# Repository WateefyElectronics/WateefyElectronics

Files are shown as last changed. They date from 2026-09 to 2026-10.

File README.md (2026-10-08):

<p align="center">
  Wateefy Electronics
</p>

<h1 align="center">Quality Engineered Electronics</h1>

<p align="center"><strong>Hardware documentation, firmware images and release mirrors.</strong></p>

---

## About

**One person. No corners cut.**

Wateefy Electronics is a one-person hardware shop building pixel-lighting gear that survives the season that kills the cheap stuff.

It started with boards that kept dying. Lighting hardware fails in predictable ways: a shorted run takes the whole board, a supply gets wired backwards for two seconds, a strip is hot-plugged and the inductive kick walks through the regulator. None of that is exotic. It is a normal season in a real installation, and most boards have nothing standing in the path to stop any of it.

So I taught myself PCB design and built the board I wanted to own — one where every failure mode has a specific part in front of it, chosen from a datasheet and verified against the copper. That board became the NODE family. The engineering discipline comes from infrastructure that is not allowed to fall over; the lights are where I get to have fun with it.

There is no team to hide behind. If something is wrong, it is on me, and I will make it right.

### How I build

**Protection first — assume it gets abused.** Reverse polarity, transients, shorted runs, backwards supplies. The board is designed for the bad day, not the bench. Nothing in the power path runs near its limit.

**Honest specs — numbers you can check.** Real ratings, real derating, real trade-offs stated out loud. No vaporware, no spec-sheet trophies that fall apart when someone does the math.

**Serviceable — repair, don't replace.** Fuses you swap by hand. A board meant to be fixed and kept running, not thrown out when one channel dies.

**Open to the community.** Docs and board definitions live here on GitHub, with mounting files as they are released. This gear is for the xLights and WLED crowd, built alongside them.

That approach scales across the catalog: pixel controllers, power distribution and injection, and whatever the next problem turns out to be.

This repository is the public documentation for that hardware. It is not the design source — schematics and layout are not published here.

---

## The NODE Platform

The NODE family is our line of addressable pixel controllers. Three boards share one power and protection architecture, differing only in how the MCU is powered and mounted — the protected power section is the product, and the module is a consumable.

| | **NODE Mini** | **NODE Flex** | **NODE Backbone** |
|---|---|---|---|
| **Control transport** | Wi-Fi | Per installed module | Wired Ethernet with PoE |
| **MCU** | Seeed XIAO ESP32-S3, socketed | Any ESP32 DevKit on 0.9″ or 1.0″ row spacing | Waveshare ESP32-S3-ETH-POE, socketed |
| **Logic power** | Onboard buck regulator from the pixel supply | Onboard buck regulator from the pixel supply | Power over Ethernet, independent of the pixel supply |
| **Built for** | Single zones on straightforward Wi-Fi sites | Mixed-hardware fleets and module obsolescence | Large installations where Wi-Fi contention becomes the limit |

### Shared architecture

Most controllers have one power rail. Input voltage lands on a terminal and it is the same copper that reaches the strips — whatever arrives, arrives everywhere at once.

NODE splits power into three isolated domains, each on its own copper plane:

1. **Dirty power in.** The input terminal is assumed hostile, isolated to the smallest region of the board possible, with nothing downstream touching it directly.
2. **Clean power.** Bidirectional transient clamping and an active reverse-polarity blocker sit between dirty and clean. Reverse the supply and the pass element never turns on — no current path, nothing sacrificed, red indicator explains why. Correct the wiring and it recovers on its own.
3. **The protected distribution bus.** Clean power passes the main fuse to become the bus. Each of the eight outputs taps that bus through its own fuse. A fault on run six opens one fuse and the other seven never notice.

Four levels of protection sit between the screw terminal and the pixels — clamp, active block, main fuse, channel fuse — each on its own copper. That is why these are four-layer boards with a split inner power plane rather than two layers and one pour.

### Common to every board

- 8 independent output channels — WS281x / SK6812 / TM1814 family, 5 V level-shifted drive
- 5–48 VDC input, no voltage jumper — one board runs 5, 12, 24 and 36 V pixel systems with nothing to set wrong
- 30 A through the board at standard 1 oz copper — not a paid upgrade
- One fuse per output channel, eight channels, no sharing
- Non-destructive reverse-polarity protection — nothing is consumed when someone wires it backwards
- Four-port DMX-512 / RS-485 output with per-port transient protection, one port receive-capable
- Per-channel data ESD protection chosen for low junction capacitance, so it does not round off WS281x bit timing on long runs
- Conformal coated at the fab — protects against moisture and humidity, with connectors, sockets, fuse clips and switches masked
- Runs WLED — pre-built images maintained for each board, no proprietary control protocol, no vendor lock-in

### Serviceable by design

Three things on these boards can be killed by field abuse, and all three pull out by hand.

**The fuse** is a mini blade — the same part sold in a variety pack at any auto parts counter. **The buffer** is a jellybean octal logic IC in a DIP socket, and the socket accepts either of two common logic families, so whichever one is in stock works. **The MCU** is a socketed module: seat another and carry on. No hot air, no braid, no scrap board.

That is what the board area buys. Blade holders, a DIP socket and terminal clearance cost real estate — room to get an iron in, room to pull a fuse without tweezers, room to reach the reset button without unmounting anything. Compact is easy. Compact and serviceable at high current is a different problem, and this is the side of it we chose. A channel that dies at eight o'clock on the twenty-third of December should be a fifteen-minute drive, not a three-day wait.

---

## Node Power

Controllers are half the problem. The other half is getting clean, protected power to where the pixels actually are — and the same three-domain thinking applies there too.

**Node Power is coming.** Details when the boards are ready, and not a day before.

---

## Documentation

Specifications are maintained per board, not in this README.

| Document | Covers |
|---|---|
| [NODE Platform Reference](./Node%20Pixel%20Controllers/README.md) | Power architecture, input protection, output stage, environmental and build data — common to all three boards. Also available as [PDF](./Node%20Pixel%20Controllers/NODE-Common-V1a.pdf) |
| [NODE Mini](./Node%20Pixel%20Controllers/Node%20Mini) | Variant specification — XIAO ESP32-S3 socket, onboard logic rail, GPIO map |
| [NODE Flex](./Node%20Pixel%20Controllers/Node%20Flex) | Variant specification — universal DevKit carrier, jumper channel mapping, module compatibility |
| [NODE Backbone](./Node%20Pixel%20Controllers/Node%20Backbone) | Variant specification — Ethernet and PoE, W5500 network stack, isolated logic domain |
| [NODE Enclosures](./Node%20Enclosures/) | Free 3D-printable enclosures: Aegis, Bastion 350, Citadel 600 |
| [Datasheets](./Datasheets) | Product datasheets in PDF |

Read the Platform Reference for how the board protects your pixels. Read the variant specification for the differences between boards.

---

## Firmware

Pre-built WLED images, configured for each board's GPIO map.

- [Node Mini (XIAO)](./Firmware/Node%20Mini/README.md)
- [Node Backbone (Waveshare)](./Firmware/Node%20Backbone/README.md)
- [All mirrored releases](https://github.com/johnvoipguy/WateefyElectronics/releases)

Images are built and maintained per board — Backbone needs its own Ethernet build, and the XIAO runs a modified build to match the Mini's GPIO map. Flash what is published here rather than a generic release.

WLED, ESPHome and ESPixelStick are properties of the ESP32 silicon, not of the carrier board, so any of them will run on any NODE board. What differs is which pre-built image ships, and how much GPIO the board's own hardware has already spent before your channels get any.

Flashing requires `esptool`. See the [firmware directory](./Firmware) for the procedure.

---

## Repository layout

```
Datasheets/               Product datasheets (PDF)
Firmware/                 Pre-built WLED images and flashing instructions
Node Enclosures/          3D-printable enclosures (3MF), photos and specs
Node Pixel Controllers/   Platform reference and per-board specifications
images/                   Product and documentation imagery
releases/                 Release notes and mirrors
```

---

## Compatibility

**LED protocols:** WS2811, WS2812/B, WS2813, WS2815, WS2816, SK6812/RGBW, TM1814, and other single-wire families supported by WLED.

**Control protocols:** E1.31/sACN, Art-Net, DDP, MQTT and the HTTP/JSON API, per WLED. DMX-512 over RS-485 on the onboard transceiver ports.

---

## Status

The NODE family is pre-release. Current hardware is a validation build — first-article boards for bring-up, characterisation and field trial. Documentation in this repository tracks that hardware and will change as revisions are finalised.

---

## Support

Open an [issue](https://github.com/johnvoipguy/WateefyElectronics/issues) for documentation errors, firmware problems or hardware questions.

---

## Accepted limitations

Stated plainly rather than buried:

- **Not automotive qualified.** Protection targets transients credible in a residential or light-commercial installation. Not tested to ISO 7637 load-dump profiles, and not intended for vehicle use.
- **Over-voltage beyond specification is not survivable.** A supply above the rated input range will conduct the input TVS and open the main fuse. This is sacrificial by design — the board is protected, and the TVS and fuse are treated as consumables.
- **No enclosure is included with the board.** Four corner mounting holes are provided for whatever the installation already uses, or print one of the free [NODE Enclosures](./Node%20Enclosures/).
- **The ecosystem is new.** Established alternatives exist with years of community documentation behind them. Each board's specification names them directly and states plainly where they are the better choice.

---

## Firmware Downloads

Use this quick selector:

- **Node Mini (XIAO)** → [Go to Mini downloads](./Firmware/Node%20Mini/README.md)
- **Node Backbone (Waveshare)** → [Go to Backbone downloads](./Firmware/Node%20Backbone/README.md)

Or browse all mirrored releases directly:  
https://github.com/johnvoipguy/WateefyElectronics/releases

<sub>© 2026 Wateefy Electronics. Specifications subject to change.</sub>

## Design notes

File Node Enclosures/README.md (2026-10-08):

# NODE Enclosures

### 3D-Printable Enclosures for the NODE Family

*Wateefy Electronics*

---

> **Free to print. Built to take the weather.**

**Document rev:** 1.0 · **Date:** 2026-10-08

---

## Overview

Three printable enclosures for NODE controllers, designed and test-printed in-house. Each
one has a fitted lid, a gland wall for every cable, and shrouded vents for an optional fan.

The print files (3MF) are free in this repository. Printed enclosures are also available in the
store, either bundled with a controller or on their own for anyone without a printer.

| | **NODE Aegis** | **NODE Bastion 350** | **NODE Citadel 600** |
|---|---|---|---|
| **Holds** | Any NODE board | NODE board + Mean Well LRS-350 | NODE board + Mean Well LRS-600 |
| **Dimensions (L × W × H)** | 187 × 153 × 46 mm | 275 × 175 × 91 mm | 275 × 175 × 99 mm |
| **Power input** | 1 × PG9 gland | 1 × PG9 gland | 1 × PG9 gland |
| **Pixel outputs** | 8 × PG7 glands | 8 × PG7 glands | 8 × PG7 glands |
| **Fan mount (optional 5 V fan)** | 3010 holes printed in | 3010 / 4010 holes printed in | 3010 / 4010 holes printed in |
| **Venting** | Shrouded vents | Shrouded vents | Shrouded vents |
| **PSU rail mounts** | — | Printable, included | Printable, included |
| **Lid** | Included | Included | Included |

---

## Common to All Three

- **Fasteners (not included):** every screw hole is printed with an M4 thread. Printed threads
  vary with printer accuracy, so use M4 self-tapping screws. Recommended lengths are 6 mm for
  the lid, and 4 mm for the NODE controller and the PSU rails.
- **Lid seal:** the top edge of the shell is stepped. A raised inner lip, about 1 mm wide and
  1.5 mm tall, runs inside the ring of screw holes and seats into a matching groove in the lid.
  The screw holes sit outside that lip, so water coming through a screw hole (loose, stripped
  or missing screw) can't get past the lid joint into the enclosure.
- **Glands:** 1 × PG9 for power in, 8 × PG7 for the pixel runs, one gland per channel.
- **Fan:** mounting holes for the fan are designed into the print: 3010 on the Aegis, 3010 or 4010
  on the Bastion and Citadel. The fan itself is optional, 5 V, and sits behind a printed vent
  shroud. The shrouds stay in place with or without a fan.
- **Ethernet (NODE Backbone, or NODE Flex with an Olimex or ETH01 module):** no Ethernet hole is pre-cut. Drill one for an M25 gland, or
  whatever size your cable and jack need.

<p align="center">
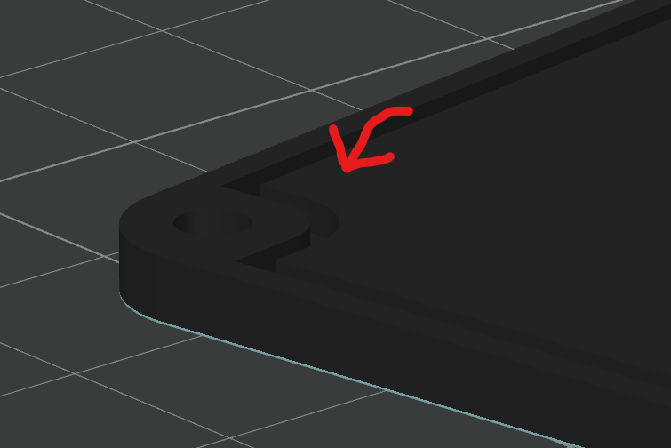
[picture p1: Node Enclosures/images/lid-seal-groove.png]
Lid underside: groove that receives the shell's inner lip
  
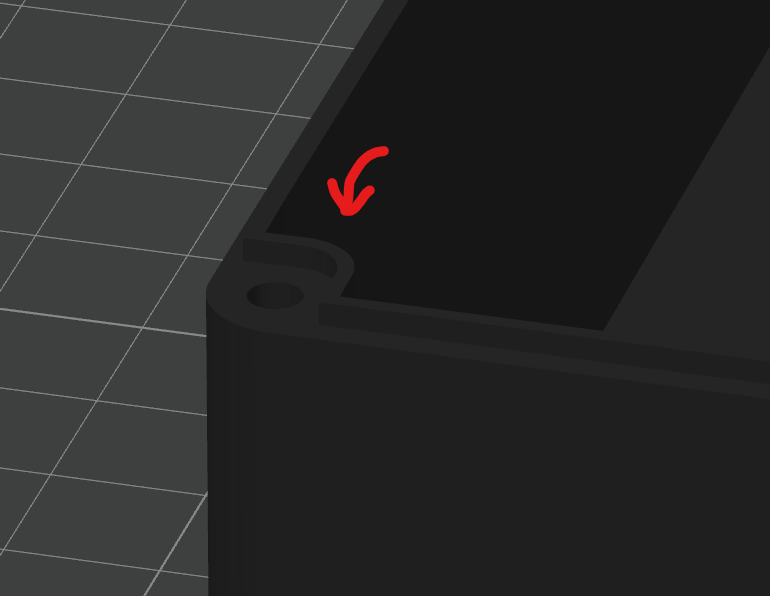
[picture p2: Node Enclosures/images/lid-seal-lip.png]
Shell top edge: raised inner lip inside the screw holes
  
</p>
<p align="center"><em>Lid seal. Left: groove in the lid. Right: inner lip on the shell, inside the screw holes.</em></p>

---

## NODE Aegis

The bare-bones enclosure. Fits any NODE controller, with no onboard PSU. Use it when power
comes from a supply mounted elsewhere.

<p align="center">
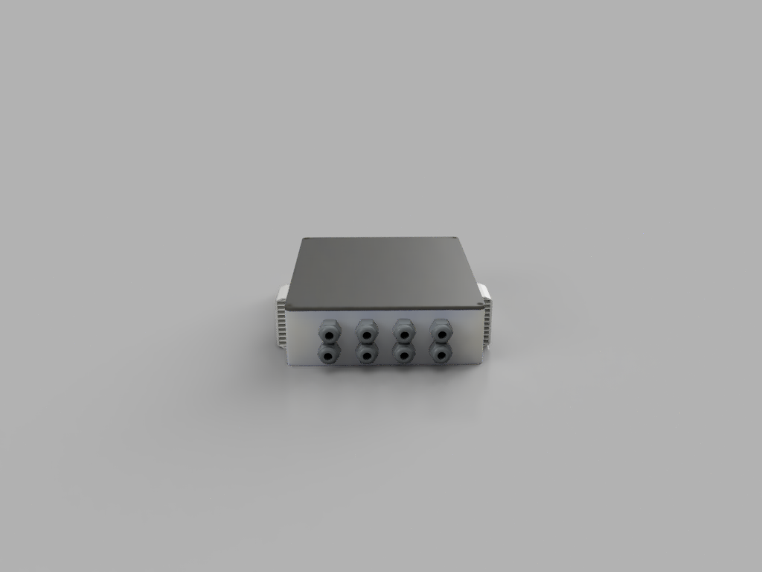
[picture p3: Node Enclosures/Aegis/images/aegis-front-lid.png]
NODE Aegis, lid on, gland wall
  
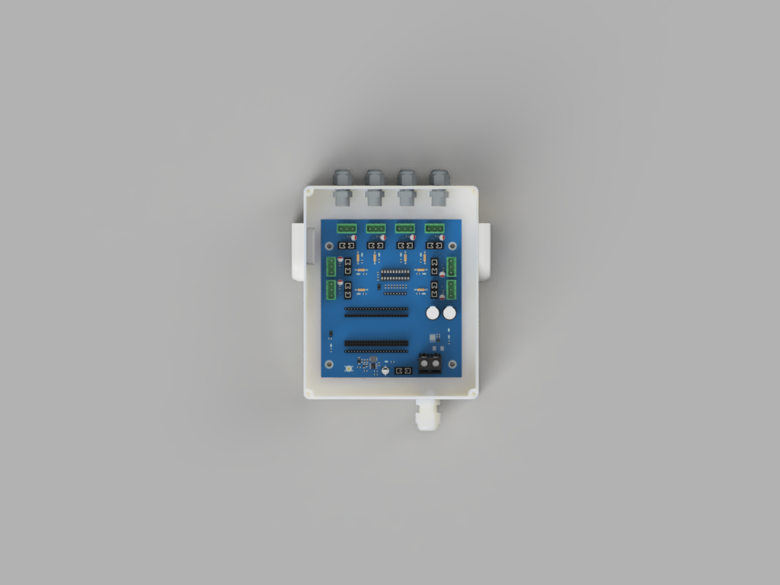
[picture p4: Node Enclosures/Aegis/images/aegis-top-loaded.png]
NODE Aegis with controller installed
  
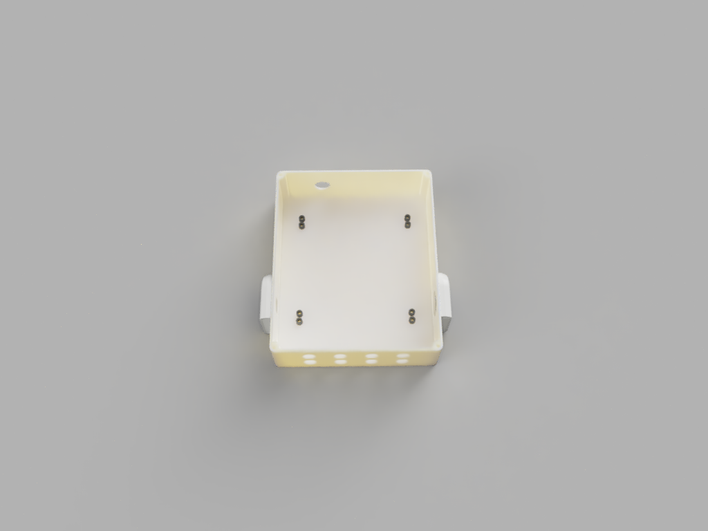
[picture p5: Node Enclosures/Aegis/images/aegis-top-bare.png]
NODE Aegis, empty shell
  
</p>

| | |
|---|---|
| Dimensions | 187 × 153 × 46 mm (L × W × H) |
| Fan | 3010 mounting holes printed in; 5 V fan optional |
| Files | [`Aegis/`](./Aegis/) |

---

## NODE Bastion 350

Controller and supply in one box. Built around the **Mean Well LRS-350**, which sits on
printable rails with the NODE board above it.

<p align="center">
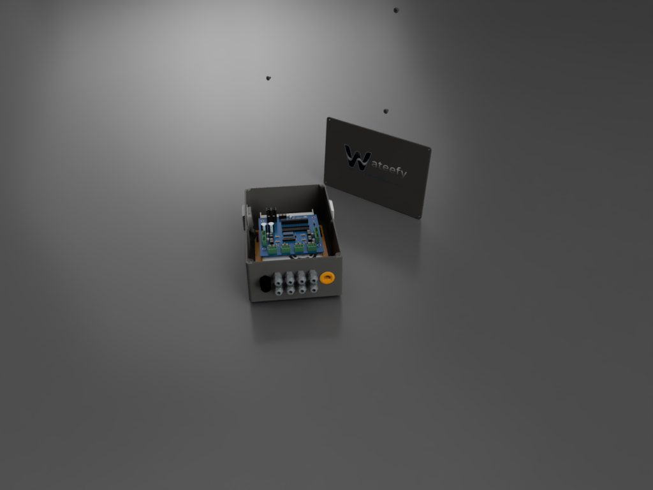
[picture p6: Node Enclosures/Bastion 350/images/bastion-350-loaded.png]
NODE Bastion 350 with controller and PSU
  
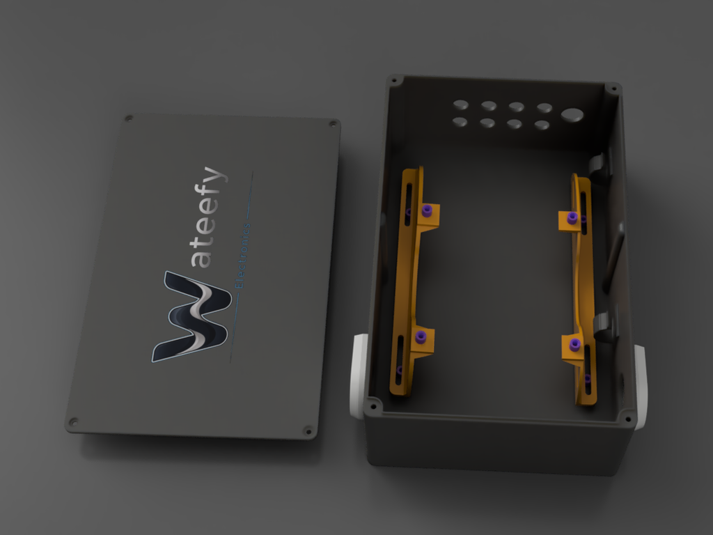
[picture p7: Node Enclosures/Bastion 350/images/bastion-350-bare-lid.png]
NODE Bastion 350 shell, PSU rails and lid
  
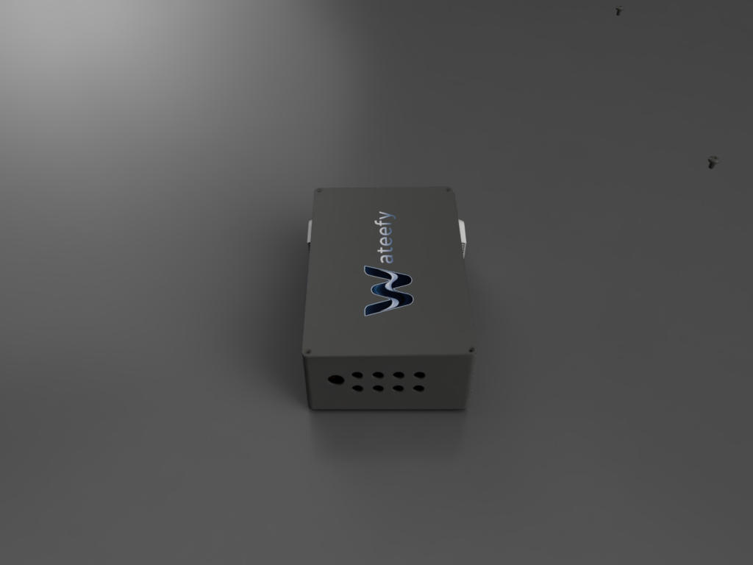
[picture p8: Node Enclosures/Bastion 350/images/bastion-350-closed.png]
NODE Bastion 350, lid on
  
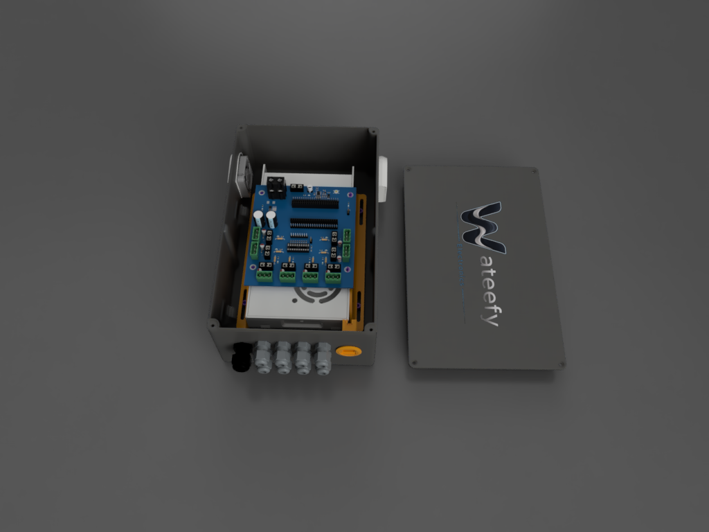
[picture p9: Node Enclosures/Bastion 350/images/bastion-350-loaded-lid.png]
NODE Bastion 350 loaded, lid alongside
  
</p>

| | |
|---|---|
| Dimensions | 275 × 175 × 91 mm (L × W × H) |
| PSU | Mean Well LRS-350, on included printable rail mounts |
| Fan | 3010 / 4010 mounting holes printed in; 5 V fan optional |
| Files | [`Bastion 350/`](./Bastion%20350/) |

---

## NODE Citadel 600

The large one. Same footprint as the Bastion, but taller to clear the **Mean Well LRS-600**.

<p align="center">
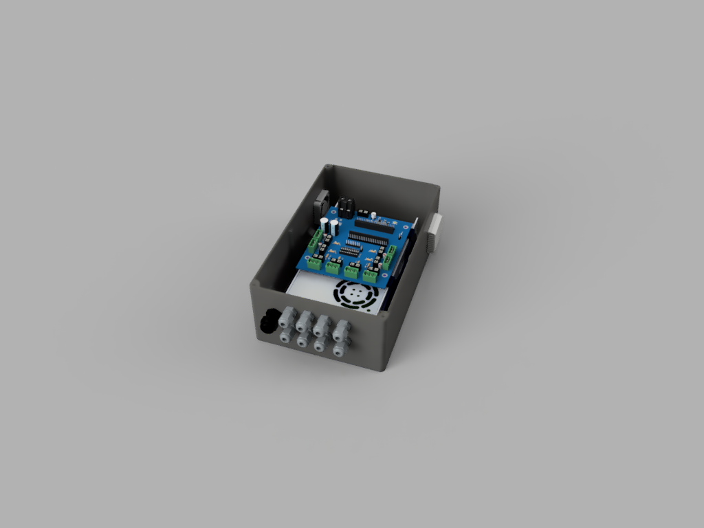
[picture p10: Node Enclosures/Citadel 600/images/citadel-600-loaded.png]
NODE Citadel 600 with controller and PSU
  
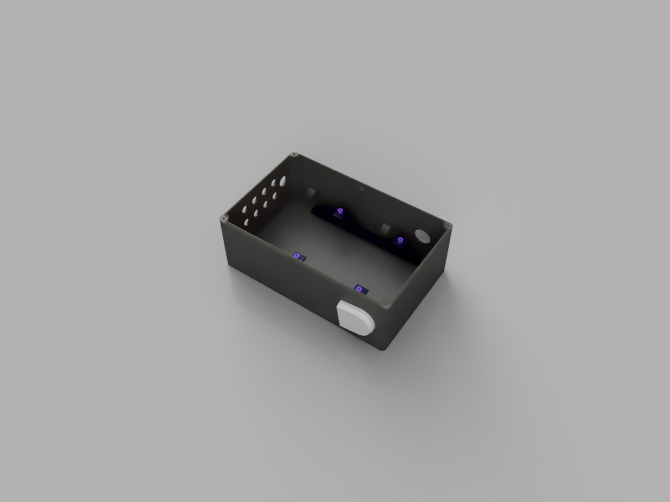
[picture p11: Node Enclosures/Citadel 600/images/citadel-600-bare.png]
NODE Citadel 600, empty shell
  
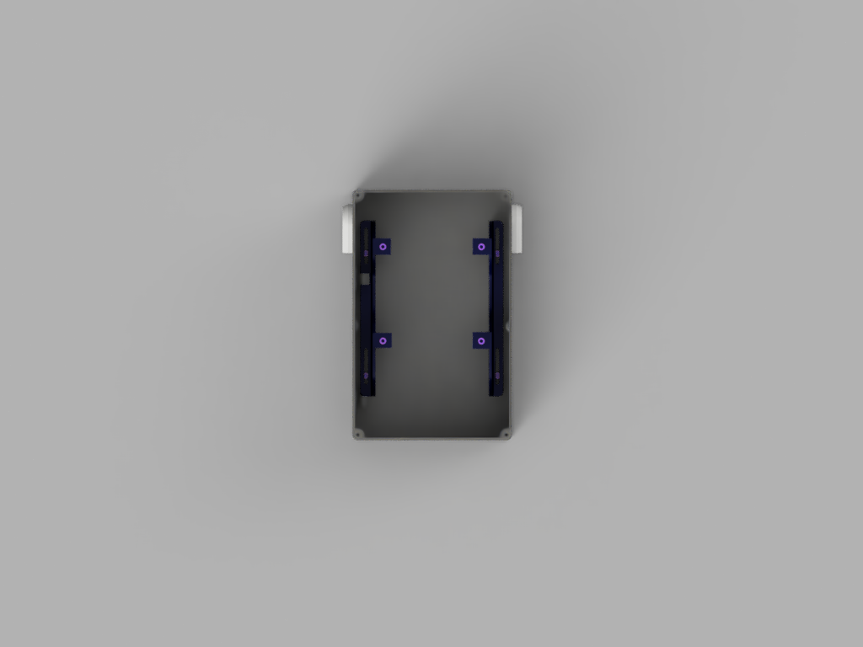
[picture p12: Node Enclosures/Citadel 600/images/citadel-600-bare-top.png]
NODE Citadel 600, top view with PSU rails
  
</p>

| | |
|---|---|
| Dimensions | 275 × 175 × 99 mm (L × W × H) |
| PSU | Mean Well LRS-600, on included printable rail mounts |
| Fan | 3010 / 4010 mounting holes printed in; 5 V fan optional |
| Files | [`Citadel 600/`](./Citadel%20600/) |

---

## Files

Each enclosure folder holds its print-ready 3MF and reference photos:

```
Node Enclosures/
├── README.md
├── Aegis/
│   ├── NODE-Aegis-Enclosure.3mf
│   └── images/
├── Bastion 350/
│   ├── NODE-Bastion-350-Enclosure.3mf
│   └── images/
└── Citadel 600/
    ├── NODE-Citadel-600-Enclosure.3mf
    └── images/
```

---

## Printing

The 3MFs are slicer project files with every part laid out on its plates: the shell, the lid,
the vent shrouds, and on the Bastion and Citadel the PSU rails. They were saved with these
reference settings:

| Setting | Value |
|---|---|
| Material | PETG |
| Nozzle | 0.4 mm |
| Layer height | 0.2 mm |
| Walls | 2 |
| Infill | 15 % |
| Supports | None |

The profile was saved on a Qidi X-Plus 5. Re-slice for your own printer. Any slicer that
reads 3MF will import the geometry.

---

*Wateefy Electronics · NODE Enclosures · Rev 1.0*

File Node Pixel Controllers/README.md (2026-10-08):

# NODE Platform

### Hardware Reference · 8-Channel Addressable LED Controller Family

*Wateefy Electronics*

---

> **The power section is the product. The module is a consumable.**

**Document rev:** 3.0 · **Board rev:** V1a · **Date:** 2026-08-06

---

## Scope

This document covers the hardware common to every board in the NODE family — power
architecture, input protection, output stage, environmental data and build process. It applies
to **NODE Mini**, **NODE Flex** and **NODE Backbone** alike.

What differs between variants — the MCU module, the logic rail source, board dimensions,
GPIO mapping and per-board accepted limitations — is documented in each board's own
**Variant Specification**. Where a variant departs from anything stated here, its supplement
says so explicitly in *Deltas from the Platform Reference*.

Read this document for how the board protects your pixels. Read the supplement for which
board to buy.

---

## 1. Power Architecture

Three separate domains, each on its own copper region:

| Domain | Boundary | What it carries |
|---|---|---|
| **Input (unprotected)** | Screw terminal → ideal-diode stage | Raw supply. Assumed hostile. Transient clamp sits across this node. |
| **Clean (protected)** | Ideal-diode output → main fuse | Reverse-blocked, surge-clamped. Bulk capacitance lives here. |
| **Distribution bus (fused)** | Main fuse → 8 channel fuses + logic regulator | Everything downstream taps this bus through its own fuse. |

## 2. Input & Protection

| Parameter | Value | Notes |
|---|---|---|
| Input voltage range | 5 – 48 VDC | Single rail, powers both pixels and onboard logic |
| Input connector | WECO 158-A-111/02, 2-pole screw terminal | 57 A / 10 mm² rated; 30 A design maximum = 53% of rating |
| Maximum continuous current | 30 A | At standard 1 oz outer copper — no copper upgrade required |
| Main fuse | 30 A mini blade, Keystone 3568 holder | Holder rated 30 A / 500 V; user-replaceable |
| Reverse-polarity protection | LM74700-Q1 ideal-diode controller + CSD18540Q5B | FET held off under reverse input; no current path to load; non-sacrificial and self-recovering |
| Pass element | CSD18540Q5B NexFET | 60 V V<sub>DS</sub>, 205 A I<sub>D</sub>, ~2.2 mΩ R<sub>DS(on)</sub> — 15% of current rating at 30 A design load |
| Input transient clamp | SMCJ48CA bidirectional TVS, 1500 W | 48 V standoff, 53.3 V breakdown; conducts in neither direction at rated input |
| Bulk capacitance | 2 × 1000 µF, 63 V | On the clean rail, downstream of the ideal diode |
| Ideal-diode charge pump | 22 nF, 100 V | VCAP to ANODE, floating — not referenced to ground |
| Ideal-diode hold-up | 47 µF electrolytic, 80 V | Between controller and pass FET, per reference design |
| Polarity indication | Anti-parallel green/red LED pair | Green = correct, red = reversed; shared 1 kΩ limit; LED reverse stress 2 V against 5 V rating |

**Voltage headroom summary:** **36 V nominal, 48 V absolute maximum.** Every component in the power path is rated **63 V or above**; every semiconductor is **60 V or above**.

**Derating against input voltage.** Utilization of each component's own rating. **5 V, 12 V and 24 V are the mainstream pixel voltages** and are shown in bold:

| Component | Rating | **5 V** | **12 V** | **24 V** | 36 V | 48 V |
|---|---|---|---|---|---|---|
| Bulk input capacitors | 63 V | **8 %** | **19 %** | **38 %** | 57 % | 76 % |
| Channel output caps | 80 V | **6 %** | **15 %** | **30 %** | 45 % | 60 % |
| Ideal-diode hold-up | 80 V | **6 %** | **15 %** | **30 %** | 45 % | 60 % |
| Buck input electrolytic | 80 V | **6 %** | **15 %** | **30 %** | 45 % | 60 % |
| HV-plane ceramics | 100 V | **5 %** | **12 %** | **24 %** | 36 % | 48 % |
| Ideal-diode controller | 65 V | **8 %** | **18 %** | **37 %** | 55 % | 74 % |
| Pass MOSFET V<sub>DS</sub> | 60 V | **8 %** | **20 %** | **40 %** | 60 % | 80 % |
| Buck regulator V<sub>IN</sub> | 80 V | **6 %** | **15 %** | **30 %** | 45 % | 60 % |

At the **36 V nominal** rating no part on the plane exceeds 60 % of its own limit. At the **48 V absolute maximum** nothing exceeds 80 %. On the 5 V, 12 V and 24 V strips that carry the overwhelming majority of installations, the entire plane runs under 40 %.

## 3. Outputs

| Parameter | Value | Notes |
|---|---|---|
| Channels | 8 | Independent, individually fused — no shared fuses |
| Output connector | Phoenix MKDS-series 3-pole, per channel | V+ / DATA / GND; 12 A rated → 63% at the 7.5 A fitted fuse, 83% at the 10 A maximum |
| Per-channel fuse | 7.5 A mini blade fitted, 10 A maximum — Keystone 3568 holder | 25% of holder rating at 7.5 A, 33% at 10 A; user-replaceable |
| Level translation | SN74HCT541 octal buffer, DIP-20 socket | 3.3 V drive vs 2.0 V V<sub>IH</sub> = 1.3 V margin |
| Data series resistance | 330 Ω, axial through-hole, per channel | Limits fault current back into the buffer |
| Data ESD protection | PESD5V0F1BL, per channel, connector side | 0.4–0.55 pF junction capacitance; RC ≈ 181 ps — no measurable effect on WS281x bit timing |
| Data drive current | ≈ 4 mA per channel | 67% of ±6 mA buffer rating |
| Buffer supply current | ≈ 45 mA total | 64% of 70 mA device maximum |
| Per-channel decoupling | 47 µF electrolytic 80 V + 100 nF ceramic 100 V | Local to each output connector |
| Channel activity indication | One LED per channel, 470 Ω limited | ≈ 5 mA, 25% of LED rating |

## 4. Environmental & Compliance

| Parameter | Value |
|---|---|
| Operating temperature | −20 °C to +60 °C *(design target; not qualification tested)* |
| Substrate rating | UL-recognized, JLC-1 marking |
| RoHS | Compliant |
| Workmanship | IPC Class 2 |
| Electrical test | Flying-probe, 100% of boards |
| Traceability | 2D barcode serial number, per board |

## Mounting & Enclosure

**No enclosure is included with the board, but three are available.** The [NODE Enclosures](../Node%20Enclosures/) are free to 3D-print from this repository, or can be bought printed from the store, on their own or bundled with a controller. **NODE Aegis** holds the board alone. **NODE Bastion 350** and **NODE Citadel 600** hold the board together with a Mean Well LRS-350 or LRS-600 supply. All three have a gland wall for power in and eight pixel runs, a sealed lid joint, and printed mounts for an optional 5 V fan.

The board still mounts just as well in whatever the installation already uses: a CG1500, a DIN rail, a weatherproof box, a plywood backer.

What NODE adds instead is **conformal coating**, applied after assembly with connectors, sockets, fuse clips, and switches masked. Competing boards in this class ship uncoated. A coated board in a vented enclosure tolerates condensation and humidity in a way a bare board does not, which matters for the seasonal outdoor installs this was built for.

Four corner mounting holes are provided. *Hole spacing and a downloadable mount STL: to be published at first article.*

---

## Build & Assurance

- **Fabrication** — 4-layer, 1.6 mm, high-T<sub>g</sub> substrate, ENIG finish, epoxy-filled and capped vias, IPC Class 2 workmanship
- **Assembly** — professional SMT assembly, flying-probe electrical test on 100% of boards
- **Traceability** — 2D barcode serial on every board; UL-recognized substrate marking
- **Coating** — conformal coating applied after assembly, with connectors, sockets, fuse clips, and switches masked
- **Design review** — every net verified against manufacturer datasheets; schematics independently reviewed by two automated analysis passes with human verification of every finding

---

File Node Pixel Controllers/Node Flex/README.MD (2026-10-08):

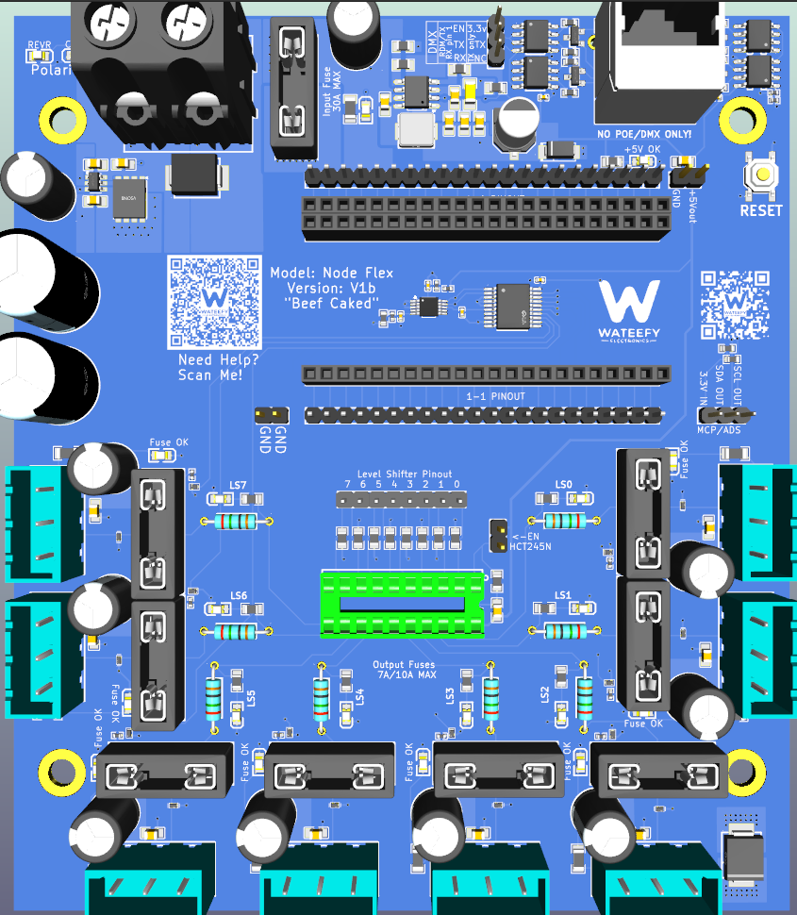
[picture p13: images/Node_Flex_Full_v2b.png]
 

                          V1                                                                   V1b

# NODE Flex

### 8-Channel Addressable LED Controller · Universal Module Carrier

*Wateefy Electronics*

> **One board. Whatever module is in the drawer.**

---

## At a Glance

- **8 independent output channels** — WS281x / SK6812 / TM1814 family, 5 V level-shifted drive
- **Any ESP32 DevKit on 0.9″ or 1.0″ row spacing** — both spacings on the board, up to 22 positions per row, jumper-mapped to the outputs
- **5–48 VDC input, no voltage jumper** — nothing to set wrong, ever
- **30 A through the board at standard copper** — not a paid upgrade
- **Three isolated power domains** — dirty input, clean protected power, fused distribution bus
- **A fuse on every single output** — eight channels, eight fuses, no sharing
- **Non-destructive reverse-polarity protection** — nothing is consumed when someone wires it backwards
- **Four-port DMX-512 / RS-485 output** — per-port transient protection, one port receive-capable
- 123 × 138 mm · 4-layer · ENIG · conformal coated

---

## Why This Exists

Every ESP32 DevKit has a different pinout. Every controller board is hard-wired to exactly one of them. So the board you bought last year is scrap when that module goes end-of-life, and the four dev boards in your parts drawer are useless because none of them match the footprint someone else chose.

NODE Flex breaks that dependency by defining compatibility as **geometry rather than a part number**. The board carries both of the common DevKit row spacings — 0.9 inch and 1.0 inch — with up to 22 positions in each row. Module length does not matter: a 2×15 or 2×19 board seats in the same sockets and simply leaves positions empty. A jumper field then decides which module pin drives which output channel.

The practical result is that the compatibility list cannot go stale. If a module lands on 0.9″ or 1.0″ centres, it fits — including modules that do not exist yet. When your favourite DevKit is discontinued, and it will be, you seat a different one and keep going. Same board, same protection, same firmware.

For anyone maintaining an installed base across mixed hardware, this is the SKU that ends the inventory problem.

---

## The Architecture: Three Power Domains

Most controllers have one power rail. Input voltage lands on a terminal and it is the same copper that reaches your strips. Whatever arrives — spike, reverse polarity, sag, transient — arrives everywhere at once.

NODE splits power into three separate domains on their own copper planes:

**1 · Dirty power in.** The input terminal accepts whatever the supply, the wiring, and the person doing the wiring hand it. This domain is assumed hostile, isolated to the smallest region of the board possible, and nothing downstream touches it directly.

**2 · Clean power.** Between dirty and clean sits the protection stage: bidirectional transient clamping and an active reverse-polarity blocker. Reverse the supply and the pass element never turns on — no current path to the rest of the board, nothing sacrificed, red indicator tells you why. Correct the wiring and it recovers on its own.

**3 · The protected bus.** Clean power passes the main fuse to become the distribution bus. Each of the eight output channels taps that bus through its own fuse. A fault on run six opens one fuse and the other seven never notice.

> **BEEFCAKE.**
> The pass element is an 80 V MOSFET whose current rating is several times the board's 30 A design load. It will never be the thing that fails.

**Decoupling where the current actually is.** Two thousand microfarads of bulk sits on the protected bus, and another forty-seven at every single output connector. The distribution is the point: one reservoir at the input cannot cover the harness inductance of eight separate output runs no matter how large it is. When a full-white frame lands on all eight channels at once, each channel draws from its own reserve sitting centimetres from its terminal.

Four levels between the screw terminal and your pixels — clamp, active block, main fuse, channel fuse — each on its own copper. That is why this is a four-layer board with a split inner power plane rather than two layers and one pour.

Nothing in the pixel power path is rated below **63 V** — and every semiconductor in it is **60 V or above** — against a 48 V absolute maximum input. Nothing in the chain runs near its limit.

At the **36 V nominal** rating, no component in the power path operates above **60 %** of its own rating. At the **48 V absolute maximum**, nothing exceeds **80 %**. On the 5 V, 12 V and 24 V strips that carry the overwhelming majority of installations, the entire plane runs under **40 %**. It is not a number anyone else in this class publishes, and it is the reason to believe the rest of this page.

---

## What Else You Actually Get

**Defined-state inputs.** Because a channel's jumper may legitimately be left unset, every buffer input carries a pull-down resistor. An unconfigured channel sits at a known logic low instead of floating and driving whatever it feels like — which on a strip full of pixels means darkness rather than noise. This is the detail that separates a real universal carrier from a breakout board with headers.

**Data lines treated like data lines.** Each output runs through a series resistor and a sub-picofarad ESD device placed on the connector side, where transients actually arrive. The low-capacitance part was chosen deliberately: a fat protection diode on a data line rounds off WS281x bit timing and produces a controller that works on the bench and sparkles on a 40-foot run.

**DMX where you need it.** Four RS-485 ports on RJ45, each with its own transceiver and its own transient protection, alongside the eight pixel channels.

> **Three things on this board can be killed by field abuse. All three pull out by hand.**
>
> **The fuse.** A mini blade — the same part sold in a variety pack at every gas station, auto parts counter and big-box store in the country. Pulls with fingers, costs pennies. Not a cartridge you order online and wait for.
>
> **The buffer.** A jellybean octal logic IC in a DIP socket. It sits directly behind your wiring, which makes it the part most likely to die and the part most annoying to replace anywhere else. Here it lifts out with a fingernail. And the socket accepts either of two common octal logic families — a strap on pin 1 handles the output-enable behaviour of one and the direction pin of the other — so you fit whichever is in stock. Supply-chain resilience on a fifty-cent line item sounds trivial right up until the next shortage.
>
> **The MCU.** A socketed module. Blow it up, seat another. No hot air, no braid, no scrap board.
>
> Nobody else in this class can claim all three.

And that is what the board area buys. Blade holders, a DIP socket, and terminal clearance cost real estate — there is room to get an iron in, room to pull a fuse without tweezers, room to reach the reset button without unmounting anything, and room at the terminals for heavy wire with ferrules. Compact is easy. Compact *and serviceable* at 30 A is a different problem, and this is the side of it we chose. A channel that dies at eight o'clock on the twenty-third of December should be a fifteen-minute drive, not a three-day wait.

**Serviceable by design.** The level shifter sits in a DIP socket. The DevKit sits in headers. Fuses pull by hand. Through-hole parts dominate the power section on purpose — this board is meant to be repaired, not replaced.

---

## Where It Goes

- **Mixed-hardware installations** — one controller SKU across a fleet built from whatever modules were available that year
- **Development and evaluation** — swap modules against a known-good, fully protected carrier
- **Long-life deployments** — the board outlives the module generation it was built around
- **Distributed whole-property displays** — one node per zone, eight runs each, scale by adding nodes

---

## How It Compares

*Comparison basis.* The closest peer is the Bong69 8 Port LED Distro — same idea, power and data integrated on one board, eight ports, WLED, sold at maker scale. QuinLED's Dig-Quad is the other reference point. Competitor figures are taken from the vendors' own published FAQ and specification pages as of July 2026 and should be re-verified before publication.

Athom's WLED range is deliberately excluded: single-strip and PWM controllers aimed at room-level and audio-reactive use. Different product, different buyer.

| | **NODE Flex** | **Bong69 8 Port LED Distro** | **QuinLED-Dig-Quad v3** |
|---|---|---|---|
| Output channels | 8 | 8 | 4 |
| MCU compatibility | Any DevKit on 0.9″ or 1.0″ row spacing, any length up to 22 positions | Fixed — WT32-ETH01 integrated | Fixed footprint — QuinLED-ESP32 or D1 Mini 32 |
| Survives module obsolescence | Yes — jumper a different DevKit | No — board is the module | No |
| Input range, one SKU | 5–48 VDC | V4: 12–48 V (5 V support dropped) · V3: 5–24 V (discontinued) | 5–24 VDC |
| Covers 5/12/24/36 V pixels | Yes, one board | No — requires choosing a version | Jumper-selectable up to 24 V; 36 V not supported |
| Input voltage selection | None — nothing to set wrong | Per board version | Jumper; vendor warns wrong setting "will fry the onboard components" |
| Input connector | Enclosed 57 A screw terminal | V4: spade connectors on a stud | Screw terminal |
| Continuous current, standard copper | 30 A | Not published | 15 A at 1 oz (30 A only with paid 2 oz upgrade) |
| Per-channel fuse rating | 7.5 A nominal · 10 A max per output | 5 A (V4) · 4 A hold / 8 A trip polyfuse (V3) | 10 A max recommended |
| Fuses on outputs | 8 — one per channel | 8 — one per channel | 5 fuses across 7 outputs (channels share) |
| Reverse-polarity protection | Active blocking — non-destructive, self-recovering | Not published | Parallel diode with fuse — sacrificial |
| Input transient clamp | Bidirectional TVS across the input | Not published | Not published |
| Data-line ESD protection | Per channel, sub-pF device | Series resistor only (33 Ω) | Not published |
| Power domain separation | 3 domains: dirty in / clean / fused bus | Not published | Single rail |
| Unconfigured input handling | Pull-down on all 8 buffer inputs | n/a — fixed pinout | n/a — fixed pinout |
| DMX-512 / RS-485 output | 4 ports, individually protected | Not published | Not published |
| Level shifter | 8-channel, socketed DIP | Not published | 4-channel, soldered |
| Conformal coating | Yes, applied at the fab | Not offered | Not offered |
| Fuse-status indicator | Per-channel LED | Blue "good fuse" LED per channel | Per board |
| Onboard USB programming | Via the module's own port | Onboard USB-C — required, the ESP is soldered down | Via the module's own port |
| Field-replaceable MCU | Yes — socketed module | No — ESP32-WROOM soldered to the board | Yes — socketed module |
| Fuse replacement | Mini blade — auto parts store, gas station, variety pack | Cartridge in a surface-mount holder — order online | ATO blade — auto parts store |
| Audio-reactive / mic support | DIY — headers fitted, spare GPIO available | DIY — wire an INMP441 to the H1 header (documented) | Analog audio input broken out |
| Temperature sensor support | DIY — headers fitted, spare GPIO available | DIY — add header, DS18B20 and 4.7 kΩ (documented) | Optional onboard footprint |
| Enclosure | Free 3D-printable [NODE Enclosures](../../Node%20Enclosures/), with or without an integrated PSU | None — 3D-print mounts published | None — bare board |
| Board size | 123 × 138 mm — the cost of blade holders, a DIP socket and terminal clearance | ~110 × 70 mm | ~100 × 50 mm |
| Firmware | WLED / ESPHome / ESPixelStick — module-level, not board-level | Same | Same |
| Firmware image | Pre-built image supplied per module | Pre-built image supplied; ESPixelStick needs the vendor hardware profile | Stock WLED builds |
| Ecosystem | New | Established, reviewed, xLights docs | Large, mature, well documented |

*A note on firmware comparisons.* WLED, ESPHome, and ESPixelStick are properties of the ESP32 silicon, not of the carrier board — any of them will run on any of these products. What actually differs is which pre-built image ships, and how much GPIO the board's own hardware has already spent before your channels get any.

**Where the others are the better choice, plainly.** Bong69 ships a proven, well-reviewed board with onboard USB-C programming, per-fuse status LEDs, documented audio-reactive and temperature-sensor support, xLights integration notes, published 3D-print mounts, and boards that arrive pre-configured and tested. QuinLED brings a deep peripheral breakout and years of community documentation. Neither ecosystem exists here yet. If you want established products, buy theirs.

**Where NODE Flex is the better choice.** Every competing board *is* its module — when that ESP32 variant goes end-of-life, the board goes with it. NODE Flex is a carrier: the module is a consumable, the protected power section is the product. Add one board covering 5/12/24/36 V pixels with every part in the power path well below its rating — no version to pick, eight fuses for eight channels, an enclosed 57 A terminal instead of exposed lugs, and four levels of protection on separate copper.

**The honest summary:** buy Bong69 or QuinLED if you want the mature ecosystem and never intend to change modules. Buy Flex if you have four different DevKits in a drawer, or if you expect to still be maintaining this installation after the current module generation is gone.

---

## Mounting & Enclosure

**No enclosure is included with the board, but three are available.** The [NODE Enclosures](../../Node%20Enclosures/) are free to 3D-print from this repository, or can be bought printed from the store, on their own or bundled with a controller. **NODE Aegis** holds the board alone. **NODE Bastion 350** and **NODE Citadel 600** hold the board together with a Mean Well LRS-350 or LRS-600 supply. All three have a gland wall for power in and eight pixel runs, a sealed lid joint, and printed mounts for an optional 5 V fan.

The board still mounts just as well in whatever the installation already uses: a CG1500, a DIN rail, a weatherproof box, a plywood backer.

What NODE adds instead is **conformal coating, applied at the fabrication facility** with connectors, sockets, fuse clips, and switches masked. Competing boards in this class ship uncoated. A coated board in a vented enclosure tolerates condensation and humidity in a way a bare board does not, which matters for the seasonal outdoor installs this was built for.

Four corner mounting holes are provided. *Hole spacing and a downloadable mount STL: to be published at first article.*

---

## Build & Assurance

- **Fabrication** — 4-layer, 1.6 mm, high-T<sub>g</sub> substrate, ENIG finish, epoxy-filled and capped vias, IPC Class 2 workmanship
- **Assembly** — professional SMT assembly, flying-probe electrical test on 100% of boards
- **Traceability** — 2D barcode serial on every board; UL-recognized substrate marking
- **Coating** — conformal coating applied at the fab, with connectors, sockets, fuse clips, and switches masked
- **Design review** — every net verified against manufacturer datasheets; schematics independently reviewed by two automated analysis passes with human verification of every finding

---

## Ordering

| Item | Detail |
|---|---|
| Model | NODE Flex |
| Configuration | Assembled, tested, conformal coated |
| Included | Controller board, level shifter installed, fuses installed |
| Not included | Enclosure (free to print or sold separately, see [NODE Enclosures](../../Node%20Enclosures/)), ESP32 DevKit module, jumper shunts, 3-pin plug connectors, blade fuses beyond those fitted, power supply |
| Availability | Pre-release. The present build is a validation run — first-article hardware for bring-up, characterisation and field trial. |
| Price | TBD |
| Lead time | TBD |
| Warranty | TBD |

---
---

# NODE Flex — Technical Specification

**Document rev:** 3.0 · **Board rev:** V1a · **Date:** 2026-09-01

> **Components are specified by function and rating.** Specific manufacturers and part
> numbers are selected at build time and may change with availability; every substitution
> is held to the ratings stated here.

## 1. Power Architecture

Three separate domains, each on its own copper region:

| Domain | Boundary | What it carries |
|---|---|---|
| **Input (unprotected)** | Screw terminal → ideal-diode stage | Raw supply. Assumed hostile. Transient clamp sits across this node. |
| **Clean (protected)** | Ideal-diode output → main fuse | Reverse-blocked, surge-clamped. Bulk capacitance lives here. |
| **Distribution bus (fused)** | Main fuse → 8 channel fuses + logic regulator | Everything downstream taps this bus through its own fuse. |

## 2. Input & Protection

| Parameter | Value | Notes |
|---|---|---|
| Pixel input voltage range | 5 – 48 VDC | 36 V nominal, 48 V absolute maximum |
| Input connector | Enclosed 2-pole screw terminal | 57 A / 10 mm² rated; 30 A design maximum = 53% of rating |
| Maximum continuous current | 30 A | At standard 1 oz outer copper — no copper upgrade required |
| Main fuse | 30 A mini blade, user-replaceable | Holder rated 30 A / 500 V |
| Reverse-polarity protection | Ideal-diode controller driving a high-side N-channel pass FET | FET held off under reverse input; no current path to load; non-sacrificial and self-recovering |
| Pass element | 80 V N-channel MOSFET, low milliohm R<sub>DS(on)</sub> | Rated above the input clamp voltage, not below it; current rating several times the 30 A design load |
| Input transient clamp | Bidirectional TVS, 1500 W, 48 V standoff | Conducts in neither direction at rated input; polarity-independent |
| Bulk capacitance | 2 × 1000 µF, 63 V | On the clean rail, downstream of the ideal diode |
| Ideal-diode support | 100 V charge-pump capacitor, 80 V hold-up capacitor | Per the controller's reference design |
| Polarity indication | Anti-parallel green/red LED pair | Green = correct, red = reversed; shared limit resistor sized for the full input range |

**Voltage headroom summary: 36 V nominal, 48 V absolute maximum.** Every component in the power path is rated **63 V or above**; every semiconductor is **60 V or above**.

**Derating against input voltage.** Utilization of each component's own rating. **5 V, 12 V and 24 V are the mainstream pixel voltages** and are shown in bold:

| Component | Rating | **5 V** | **12 V** | **24 V** | 36 V | 48 V |
|---|---|---|---|---|---|---|
| Bulk input capacitors | 63 V | **8 %** | **19 %** | **38 %** | 57 % | 76 % |
| Channel output caps | 80 V | **6 %** | **15 %** | **30 %** | 45 % | 60 % |
| Ideal-diode hold-up | 80 V | **6 %** | **15 %** | **30 %** | 45 % | 60 % |
| HV-plane ceramics | 100 V | **5 %** | **12 %** | **24 %** | 36 % | 48 % |
| Ideal-diode controller | 65 V | **8 %** | **18 %** | **37 %** | 55 % | 74 % |
| Pass MOSFET V<sub>DS</sub> | 80 V | **6 %** | **15 %** | **30 %** | 45 % | 60 % |

At the **36 V nominal** rating no part on the plane exceeds 60 % of its own limit. At the **48 V absolute maximum** nothing exceeds 80 %. On the 5 V, 12 V and 24 V strips that carry the overwhelming majority of installations, the entire plane runs under 40 %.

## 3. 5 V Logic Rail

| Parameter | Value | Notes |
|---|---|---|
| Regulator | Wide-input synchronous buck, thermally-padded package | Sat on the distribution bus; 12 thermal vias under the pad |
| Absolute maximum input | 80 V class | Well above the 48 V absolute-maximum input |
| Switching frequency | 400 kHz | Set by a fixed timing resistor |
| Output voltage | 5.1 V nominal | Resistive divider against a 1.0 V reference |
| Output current capability | 2 A | Actual load ≈ 0.5 A → 25% utilization |
| Inductor | 15 µH, 3.0 A saturation, 2.5 A RMS | 79% of saturation rating at the full 2 A load |
| Output capacitance | 3 × 22 µF ceramic | Per regulator reference design |
| Input capacitance | 4.7 µF + 100 nF ceramic, 100 V X7R, plus 80 V electrolytic bulk | Rated for the full input range with derating headroom |
| 5 V rail clamp | Unidirectional TVS, 6 V standoff | Cathode to the +5 V rail, anode to ground |
| Minimum on-time margin | 2.7× at 36 V input | No frequency foldback anywhere in the input range |
| Manual reset | Momentary switch to regulator enable | Pull-up to the distribution bus |

## 4. Outputs

| Parameter | Value | Notes |
|---|---|---|
| Channels | 8 | Independent, individually fused — no shared fuses |
| Output connector | 3-pole pluggable terminal, per channel | V+ / DATA / GND; 12 A rated → 63% at the 7.5 A fitted fuse, 83% at the 10 A maximum |
| Per-channel fuse | 7.5 A mini blade fitted, 10 A maximum | 25% of holder rating at 7.5 A, 33% at 10 A; user-replaceable |
| Level translation | Octal logic buffer, DIP-20 socket | Accepts either of two common octal families; 3.3 V drive against a 2.0 V V<sub>IH</sub> = 1.3 V margin |
| Data series resistance | 330 Ω, axial through-hole, per channel | Limits fault current back into the buffer |
| Data ESD protection | Sub-picofarad ESD device, per channel, connector side | 0.4–0.55 pF junction capacitance; RC ≈ 181 ps — no measurable effect on WS281x bit timing |
| Data drive current | ≈ 4 mA per channel | 67% of the ±6 mA buffer rating |
| Buffer supply current | ≈ 45 mA total | 64% of the 70 mA device maximum |
| Per-channel decoupling | 47 µF electrolytic 80 V + 100 nF ceramic 100 V | Local to each output connector |
| Channel activity indication | One LED per channel | Data activity on that channel |
| Fuse-status indication | One LED per channel, fed from the post-fuse node | Lit = that channel's fuse is intact and the bus is live |
| Buffer input pull-downs | 10 kΩ to ground, all 8 inputs | Defines logic low when a channel jumper is not fitted; ~330 µA sink at logic high |

### 4b. DMX-512 / RS-485 Output

| Parameter | Value | Notes |
|---|---|---|
| Ports | 4 | RJ45, T568B pairing |
| Transceivers | One RS-485 transceiver per port | Driver enables tied to a shared enable net; transmit data shared across all four |
| Receive | Port 1 only | The remaining three ports are transmit-only by design |
| Port protection | TVS array on the connector-side net, plus series resistance per line | Clamp sits ahead of the series limiting, in that order |

## 5. MCU Interface & Firmware

| Parameter | Value |
|---|---|
| Module support | Any ESP32-family DevKit on a supported row spacing *(module not included)* |
| Supported row spacings | 0.9″ (22.86 mm) and 1.0″ (25.4 mm) — both provided on the board |
| Socket rows | 2.54 mm pitch, up to 22 positions per row |
| Module length | Not constrained — shorter modules (2×15, 2×19) seat in the same rows, leaving positions unused |
| Channel assignment | Jumper header maps module GPIO to each of the 8 buffer inputs |
| Unconfigured channels | Held low by pull-down — no floating inputs |
| Buffer enable | Strap-selectable buffer output enable |
| Firmware | WLED — pre-built image supplied, configured for the fitted module's GPIO map |
| Supported LED protocols | WS2811, WS2812/B, WS2813, WS2815, WS2816, SK6812/RGBW, TM1814, and other single-wire families supported by WLED |
| Connectivity | Per installed module — Wi-Fi 2.4 GHz, or wired Ethernet / PoE-Ethernet where the DevKit provides it |
| Verified Ethernet DevKits | WT32-ETH01, WT32-ETH01-EVO and WT32-ETH02-PLUS all sit on 0.9″ (22.86 mm) centres and seat directly, leaving one free socket row per side |
| Known non-fitting modules | Olimex and LilyGo boards use non-standard row spacings and will not seat directly — they require an adapter or hand-wiring. Check your module's row centres against 0.9″ / 1.0″ before ordering |
| Control protocols | Per WLED: E1.31/sACN, Art-Net, DDP, MQTT, HTTP/JSON API. DMX-512 over the onboard RS-485 ports |
| Additional I/O | Spare module GPIO broken out on fitted headers for I²C and SPI peripherals, plus 3.3 V / 5 V / GND / TX / RX. Availability depends on the fitted DevKit |

> **Integrator note:** confirm that the GPIO assigned to a channel is not a boot-strapping pin on your specific module, and is free of flash or PSRAM duties. Pin restrictions vary by module and remain the integrator's responsibility.

## 6. Physical

| Parameter | Value |
|---|---|
| PCB dimensions | 123 × 138 mm |
| PCB thickness | 1.6 mm |
| Layer count | 4 — signal / ground plane / split power plane / signal |
| Copper weight | 1 oz outer, 1 oz inner |
| Substrate | High-T<sub>g</sub> 155 °C |
| Surface finish | ENIG, 1 µ" gold |
| Via treatment | Epoxy filled and capped |
| Soldermask | Blue |
| Mounting | 4 × corner mounting holes, 3 mm |
| Mounting hole spacing | 107.9 × 103.8 mm |
| Enclosure | Free 3D-printable [NODE Enclosures](../../Node%20Enclosures/), with or without an integrated PSU |
| Net weight | TBD — measure at first article |
| Conformal coating | Applied at the fab; connectors, sockets, fuse clips, and switches masked |

## 7. Environmental & Compliance

| Parameter | Value |
|---|---|
| Operating temperature | −20 °C to +60 °C *(design target; not qualification tested)* |
| Substrate rating | UL-recognized, JLC-1 marking |
| RoHS | Compliant |
| Workmanship | IPC Class 2 |
| Electrical test | Flying-probe, 100% of boards |
| Traceability | 2D barcode serial number, per board |

## 8. Design Notes & Accepted Limitations

Stated plainly rather than buried:

- **Not automotive qualified.** Protection targets transients credible in a residential or light-commercial installation. Not tested to ISO 7637 load-dump profiles; not intended for vehicle use.
- **Worst-case clamp coordination.** At the TVS datasheet maximum clamping voltage under a full rated pulse, the voltage presented to downstream components exceeds their ratings. That condition requires a pulse energy source which does not exist in a mains-fed low-voltage installation, and is accepted as non-credible for the intended deployment. At realistic clamp currents the entire downstream chain retains margin.
- **Over-voltage beyond specification is not survivable.** A supply above the rated input range will conduct the input TVS and open the main fuse. Sacrificial by design — the board is protected, the TVS and fuse are consumables.
- **Module compatibility is defined mechanically, and validated electrically by the integrator.** Any DevKit on 0.9″ or 1.0″ row spacing will seat. Whether a given GPIO on that module can drive an output channel is a separate question: strapping pins, flash and PSRAM duties, and input-only pins differ by module and must be checked against the module's own documentation before assigning channels. Olimex and LilyGo boards use non-standard row spacings and will not drop straight in — they need an adapter or hand-wiring to reach the socket rows.
- **Load capability.** The 5 V rail powers onboard logic and indicators only. Pixel power comes directly from the distribution bus; total system current is bounded by the 30 A main fuse and the user's supply.

---

*Wateefy Electronics · NODE Flex · Specifications subject to change.*

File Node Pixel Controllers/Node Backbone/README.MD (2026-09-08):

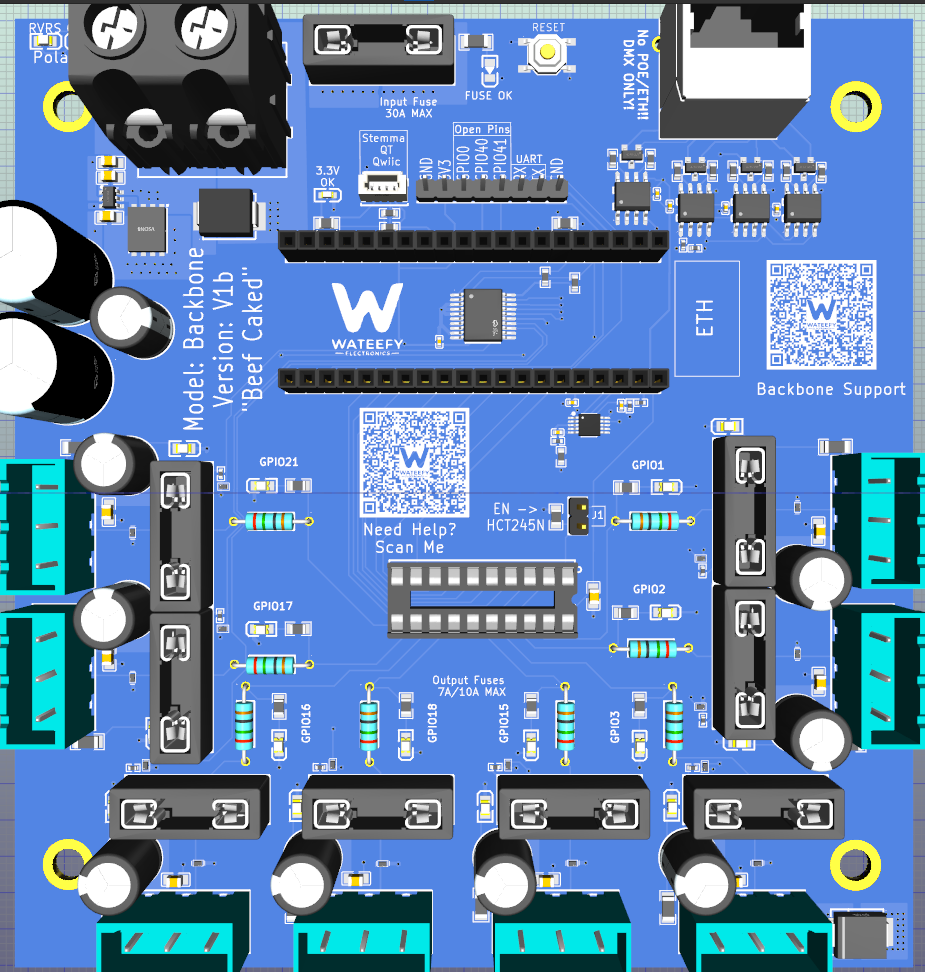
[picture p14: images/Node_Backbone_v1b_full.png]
 

                          V1                                                                   V1b

<p align="center">
  
  
  
  
  
  
  
  

  </p>

# Welcome! ✨

A fast and feature-rich implementation of an ESP8266/ESP32 webserver to control NeoPixel (WS2812B, WS2811, SK6812) LEDs or also SPI based chipsets like the WS2801 and APA102!

## 🔌 Waveshare ESP32-S3-ETH Custom Build

This is a custom WLED build for the **Waveshare ESP32-S3-ETH** board with W5500 Ethernet support.

### 🚀 Quick Start (Get Flashing!)

**📥 Download Latest Firmware:**

**⚠️ Use v17** — this is the firmware line with full Ethernet protocol support (E1.31, Art-Net, DDP, MQTT over Ethernet). v16 is archived and does not route WLED protocols through Ethernet.

- Wrong network behavior or missing Ethernet: verify you flashed the v17 Waveshare target build.
- OTA failures: flash `.full.bin` over UART and retry setup.
 
Latest v17 builds:
https://github.com/johnvoipguy/WateefyElectronics/releases (filter for `waveshare-esp32s3-eth-v17`)

All releases:
https://github.com/johnvoipguy/WateefyElectronics/releases

**⚡ Flash Commands (v17):**

First time or after factory reset (use FULL.bin):
```bash
esptool.py --chip esp32s3 --port /dev/ttyACM0 --baud 921600 \
  write_flash 0x0 firmware/WLED_Waveshare_ESP32-S3-ETH_*_FULL.bin
```

OTA update on already-running board (use APP.bin, preserves settings):
```bash
esptool.py --chip esp32s3 --port /dev/ttyACM0 --baud 921600 \
  write_flash 0x10000 firmware/WLED_Waveshare_ESP32-S3-ETH_*_APP.bin
```

Replace `/dev/ttyACM0` with your serial port (Windows: `COM3`, `COM4`, etc.)

Alternatively, use web-based flasher: [ESPConnect](https://thelastoutpostworkshop.github.io/ESPConnect/)

### Hardware Configuration
- **Board**: Waveshare ESP32-S3-ETH (ESP32-S3, 16MB Flash, 8MB PSRAM) — v1a hardware
- **Ethernet**: W5500 SPI Ethernet (pins: MISO=12, MOSI=11, SCLK=13, CS=14, RST=9, INT=10)
- **LED Outputs**: 8 channels configured (GPIO 0, 1, 2, 3, 15, 18, 16, 17) — hardware-driven via 4 RMT + parallel I2S
  - **Note for v1b:** Proposed GPIO0→GPIO21 swap pending; when v1b ships, update this list and firmware accordingly
- **Status LED**: GPIO21 (onboard, not available for pixel output)

### Network Configuration

**v17 interface behavior:**
- **Ethernet (W5500)**: Wired 10/100 Mbps, carries E1.31, Art-Net, DDP, MQTT — full protocol support
- **WiFi**: Backup access carries E1.31, Art-Net, DDP, MQTT, webadmin — full protocol support (active only when Ethernet is disconnected)

#### Initial Setup Procedure
1. **First boot** (without Ethernet cable):
   - Device creates AP: `WLED-ETH-Config` (open, no password)
   - Connect to AP and configure WiFi via web interface (http://4.3.2.1)
   - Save settings and reboot

2. **Subsequent boots** (with Ethernet cable connected):
   - Ethernet: Gets DHCP address automatically (e.g., 192.168.50.239)
   - WiFi: Connects to configured SSID (e.g., 192.168.50.230)
   - Both interfaces active simultaneously — use Ethernet for LED streaming

#### Interface Capabilities (v17)

**Ethernet Interface** (primary for LED control):
- ✅ E1.31/sACN, Art-Net, DDP — **full protocol support over wire**
- ✅ MQTT
- ✅ HTTP/JSON API
- ✅ Web interface
- ✅ Ping/ICMP
- ✅ Low-latency, deterministic LED streaming

**WiFi Interface** (Initial configuration after flash and backup if no Ethernet):
- ✅ Full web interface (webadmin)
- ✅ E1.31 (sACN), Art-Net, DDP, MQTT — full protocol support
- ✅ HTTP/JSON API and WebSockets
- ✅ OTA updates
- ✅ Automatic activation when Ethernet is disconnected

#### Recommended Usage
- **Primary control**: Ethernet for xLights, sACN, Art-Net, and MQTT streaming
- **Configuration**: Web interface via Ethernet IP (primary) or WiFi if needed
- **Note on this firmware**: Waveshare v17 disables WiFi when Ethernet is connected. Other boards with different firmware keep both interfaces active.

### Technical Notes

v17 uses W5500 as a native Ethernet MAC/PHY interface (lwIP stack on ESP32 cores). This differs from v16's attempted hardware-socket offload, which proved non-functional — no WLED protocols actually reached Ethernet in v16. v17 trades some MCU cycles for correctness: the network stack runs in software, but every protocol that binds to lwIP works over Ethernet automatically.

### 🔧 Configuration Guide

#### First-Time Setup (WiFi Configuration Required)

**⚠️ CRITICAL: WiFi must be configured before Ethernet is connected.** This firmware disables WiFi when Ethernet cable is detected.

**Step 1: Initial Boot — NO Ethernet Cable**
1. Power on the board with **NO Ethernet cable connected**
2. Device creates open AP: `WLED-ETH-Config` (no password)
3. Connect phone/computer to this AP
4. Browser auto-opens to `http://4.3.2.1` (or navigate manually)
5. Go to **Config → WiFi Setup**
6. Enter your WiFi SSID and password
7. Click **Save & Reboot**

**Step 2: Connect Ethernet (WiFi will disable)**
1. After WiFi reboots and connects, plug Ethernet cable into RJ45 port
2. **WiFi automatically disables when Ethernet link is detected** — only one interface active at a time
3. Device gets **Ethernet IP** (check your router's DHCP list, e.g., 192.168.50.239)
4. Web interface accessible via **Ethernet IP only** until cable is unplugged (then WiFi auto-resumes)

**Step 3: Configure LED Settings**
1. Access web interface via Ethernet: `http://192.168.50.239` (or use mDNS: `http://wled-<chipid>.local`)
2. Go to **Config → LED Preferences**
3. Default LED pins: GPIO 0–7 (8 independent channels)
   - **Outputs 1–4**: Hardware RMT drivers (recommended for timing-critical strips like WS2812B)
   - **Outputs 5–8**: Software I2S drivers (automatic, no manual configuration needed)
4. Select LED type per channel (WS2812B, SK6812, WS2811, etc.)
5. Set LED count per channel
6. Click **Save** — no reboot required

**Step 4: Configure LED Streaming Protocol (Optional)**
1. Go to **Config → Sync Interfaces**
2. Select your LED control protocol: **E1.31 (sACN), Art-Net, or DDP** (recommended)
3. Set UDP port if needed (default: E1.31 = 5568, Art-Net = 6454, DDP = 4048)
4. Save and test from your control software (xLights, Vixen, etc.)

#### Network Settings (Pre-Configured)
- **Ethernet Type**: W5500 SPI (Type 13)
- **DHCP**: Enabled automatically
- **mDNS**: `http://wled-<chipid>.local` available after WiFi setup

#### Available GPIO for Usermods and Peripherals

If you want to add custom functionality (temperature sensors, extra I/O, microphone input, etc.):

- **GPIO 38–41**: Available for usermods (I²C, SPI, analog input, etc.)
- **GPIO4**: Reserved for SD card (if future SD card support is added)

**Do NOT use:**
- GPIO 0–3, 15–18: LED data outputs
- GPIO 4–7: SD card (reserved for future SD card support)
- GPIO 9–14: W5500 Ethernet SPI (CS, RST, INT, MOSI, SCLK, MISO)
- GPIO 21: Onboard status LED
- GPIO 33–37: Module PSRAM (unavailable)

#### Important Notes
- ⚠️ **WiFi MUST be configured first** (Step 1) before connecting Ethernet cable
- ⚠️ **Ethernet disables WiFi** — this is firmware behavior on this board, not a defect
- ✅ Access web interface via **Ethernet IP only** when cable is connected
- ✅ **Use Ethernet for E1.31/Art-Net/DDP** — low-latency, deterministic streaming (recommended over WiFi)
- ✅ Unplug Ethernet cable to re-enable WiFi (e.g., for wireless troubleshooting)

## ⚙️ WLED Features

This board runs **WLED** — open-source LED controller firmware. Key features:

- **8 independent LED outputs** (this board: GPIO 0–3, 15–18)
- WS2812FX library with 100+ special effects  
- FastLED noise effects and 50 palettes  
- Modern web UI with color, effect, and segment controls  
- Segments to set different effects/colors to user-defined LED ranges  
- Up to 250 user presets with automatic playback cycling  
- Presets can trigger API calls  
- Full network configuration via settings page  
- Access Point (AP) and Station mode with automatic failsafe AP  
- Support for RGBW and other LED strip types
- Nightlight function (gradual dimming)  
- Full OTA firmware updates (HTTP + ArduinoOTA), password-protectable  
- Configurable auto-brightness limiting for safe operation  
- Filesystem-based config backup/restore  

## 💡 Supported light control interfaces
- WLED app for [Android](https://play.google.com/store/apps/details?id=com.aircoookie.WLED) and [iOS](https://apps.apple.com/us/app/wled/id1475695033)
- JSON and HTTP request APIs  
- MQTT   
- E1.31, Art-Net, DDP and TPM2.net
- [diyHue](https://github.com/diyhue/diyHue) (Wled is supported by diyHue, including Hue Sync Entertainment under udp. Thanks to [Gregory Mallios](https://github.com/gmallios))
- [Hyperion](https://github.com/hyperion-project/hyperion.ng)
- UDP realtime  
- Alexa voice control (including dimming and color)  
- Sync to Philips hue lights  
- Adalight (PC ambilight via serial) and TPM2  
- Sync color of multiple WLED devices (UDP notifier)  
- Infrared remotes (24-key RGB, receiver required)  
- Simple timers/schedules (time from NTP, timezones/DST supported)  

## 📲 WLED Documentation

For complete WLED documentation, features, and tutorials:
- **WLED Knowledge Base**: https://kno.wled.ge
- **WLED Project Site**: https://wled.me
- **Tutorials & Guides**: https://kno.wled.ge/basics/tutorials/

## 🤝 Community & Support

**WLED Project:**
- Licensed under the EUPL v1.2 license  
- [Project Credits](https://kno.wled.ge/about/contributors/)
- [Discord Community](https://discord.gg/QAh7wJHrRM)
- [Forum](https://wled.discourse.group)

Check out the WLED [Discourse forum](https://wled.discourse.group)!  

You can also send me mails to [dev.aircoookie@gmail.com](mailto:dev.aircoookie@gmail.com), but please, only do so if you want to talk to me privately.  

If WLED really brightens up your day, you can 

*Disclaimer:*   

If you are prone to photosensitive epilepsy, we recommended you do **not** use this software.  
If you still want to try, don't use strobe, lighting or noise modes or high effect speed settings.

As per the EUPL license, I assume no liability for any damage to you or any other person or equipment.

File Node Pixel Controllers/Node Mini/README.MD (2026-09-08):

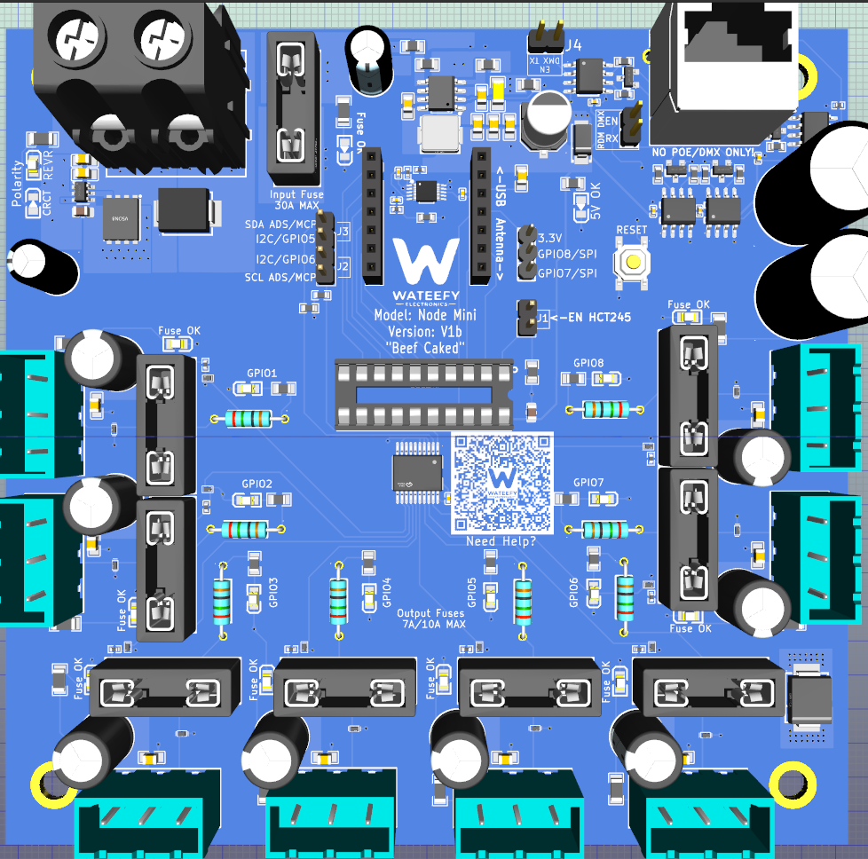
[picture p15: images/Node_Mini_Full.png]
       

                          V1                                                                   V1b

# Node Mini Firmware (XIAO)
This page is the quick user entrypoint for Seeed Xiao ESP32S3 firmware in this repo.

## Which file should I flash?

- `.app.bin` for OTA updates on an already-running device.
- `.full.bin` for first-time USB/UART flash or recovery.

## Flashing

### OTA

Use WLED UI: Settings -> Security & Updates -> Manual OTA.

### UART (first-time / recovery)

```sh
esptool.py --chip esp32s3 write_flash 0x0000 <your-file>.full.bin
```
- Or if you prefer web-based flasher:  [ESPConnect](https://thelastoutpostworkshop.github.io/ESPConnect/)
  
Latest:
- [seeed-xiao-esp32s3-v16-seeed_xiao_esp32s3v2-e1ca36c (mirrored)](https://github.com/johnvoipguy/WateefyElectronics/releases/tag/mirror-seeed-xiao-esp32s3-v16-seeed_xiao_esp32s3v2-e1ca36c)

Recent builds:
- [seeed-xiao-esp32s3-v16-seeed_xiao_esp32s3v2-e1ca36c (mirrored)](https://github.com/johnvoipguy/WateefyElectronics/releases/tag/mirror-seeed-xiao-esp32s3-v16-seeed_xiao_esp32s3v2-e1ca36c)
- [seeed-xiao-esp32s3-v15-seeed_xiao_esp32s3v2-9a42371 (mirrored)](https://github.com/johnvoipguy/WateefyElectronics/releases/tag/mirror-seeed-xiao-esp32s3-v15-seeed_xiao_esp32s3v2-9a42371)
- [seeed-xiao-esp32s3-v15-seeed_xiao_esp32s3v2-5afc742 (mirrored)](https://github.com/johnvoipguy/WateefyElectronics/releases/tag/mirror-seeed-xiao-esp32s3-v15-seeed_xiao_esp32s3v2-5afc742)
- [seeed-xiao-esp32s3-nightly-seeed_xiao_esp32s3v2-d8018a2 (mirrored)](https://github.com/johnvoipguy/WateefyElectronics/releases/tag/mirror-seeed-xiao-esp32s3-nightly-seeed_xiao_esp32s3v2-d8018a2)
- [LEGACY seeed_xiao_esp32s3v2E WLED Firmware - 2026-05-21 22:26 (mirrored)](https://github.com/johnvoipguy/WateefyElectronics/releases/tag/mirror-seeed_xiao_esp32s3v2-v20260521-222612)

All releases:
https://github.com/johnvoipguy/WateefyElectronics/releases

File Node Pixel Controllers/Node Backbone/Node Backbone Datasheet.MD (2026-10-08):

# NODE Backbone

### 8-Channel Addressable LED Controller · Ethernet + PoE Node

*Wateefy Electronics*

> **Wired control. The network powers the node.**

---

## At a Glance

- **8 independent output channels** — WS281x / SK6812 / TM1814 family, 5 V level-shifted drive
- **Wired Ethernet on dedicated silicon** — W5500 controller with its own MAC, PHY and hardware TCP/IP stack
- **Power over Ethernet** — the switch powers the controller; no separate supply for the electronics
- **5–48 VDC pixel input, no jumpers** — separate rail for strip power, nothing to set wrong
- **30 A through the board at standard copper** — not a paid upgrade
- **Three isolated pixel power domains** plus an independent network-powered logic domain
- **A fuse on every single output** — eight channels, eight fuses, no sharing
- **Four-port DMX-512 / RS-485 output** — per-port transient protection, one port receive-capable
- 123 × 129 mm · 4-layer · ENIG · conformal coated

---

## Why This Exists

Wi-Fi is fine until it isn't. Put twelve controllers on one property, push sixty frames a second of sACN at all of them, and the failure mode is not a clean disconnect — it is stutter, tearing, and one zone that goes dark for four seconds during the show. Adding access points helps until the 2.4 GHz band gives up.

NODE Backbone puts the control plane on wire. Each node gets an Ethernet drop; the switch powers the logic and carries the data. Frame timing becomes deterministic, the controller shows up in your DHCP table like every other piece of infrastructure, and troubleshooting becomes a link light instead of a signal-strength guess.

This is the SKU for the installation that outgrew Wi-Fi.

---

## The Architecture: Three Power Domains

Most controllers have one power rail. Input voltage lands on a terminal and it is the same copper that reaches your strips. Whatever arrives — spike, reverse polarity, sag, transient — arrives everywhere at once.

NODE splits power into three separate domains on their own copper planes:

**1 · Dirty power in.** The input terminal accepts whatever the supply, the wiring, and the person doing the wiring hand it. This domain is assumed hostile, isolated to the smallest region of the board possible, and nothing downstream touches it directly.

**2 · Clean power.** Between dirty and clean sits the protection stage: bidirectional transient clamping and an active reverse-polarity blocker. Reverse the supply and the pass element never turns on — no current path to the rest of the board, nothing sacrificed, red indicator tells you why. Correct the wiring and it recovers on its own.

**3 · The protected bus.** Clean power passes the main fuse to become the distribution bus. Each of the eight output channels taps that bus through its own fuse. A fault on run six opens one fuse and the other seven never notice.

**And a fourth domain, entirely separate: the network side.** Logic power arrives over Ethernet, on its own ground domain, joined to board ground at one deliberate point. The control plane and the high-current pixel return are treated as a design problem rather than an accident of layout — the difference between a board that passes on a bench and one that behaves across long runs and multiple supplies.

> **BEEFCAKE.**
> The pass element is an 80 V MOSFET whose current rating is several times the board's 30 A design load. It will never be the thing that fails.

**Decoupling where the current actually is.** Two thousand microfarads of bulk sits on the protected bus, and another forty-seven at every single output connector. The distribution is the point: one reservoir at the input cannot cover the harness inductance of eight separate output runs no matter how large it is. When a full-white frame lands on all eight channels at once, each channel draws from its own reserve sitting centimetres from its terminal.

Four levels between the screw terminal and your pixels — clamp, active block, main fuse, channel fuse — each on its own copper. That is why this is a four-layer board with a split inner power plane rather than two layers and one pour.

Nothing in the pixel power path is rated below **63 V** — and every semiconductor in it is **60 V or above** — against a 48 V absolute maximum input. Nothing in the chain runs near its limit.

At the **36 V nominal** rating, no component in the power path operates above **60 %** of its own rating. At the **48 V absolute maximum**, nothing exceeds **80 %**. On the 5 V, 12 V and 24 V strips that carry the overwhelming majority of installations, the entire plane runs under **40 %**. It is not a number anyone else in this class publishes, and it is the reason to believe the rest of this page.

---

## What Else You Actually Get

**A real network node.** Wired 10/100 Ethernet with PoE means the logic side needs nothing but the drop. Run pixel power to the enclosure on conductors sized for the load and let the network cable handle control and controller power. Fewer supplies, fewer failure points, and a control path that behaves the same at node twelve as at node one.

**Reachable even when the pixel supply is off.** Because logic power comes over Ethernet, the node stays on the network with the strip supply dark. Useful for pre-season configuration and for telling "controller down" apart from "supply down" without a ladder.

**Ethernet on dedicated silicon.** The ESP32-S3 has no built-in Ethernet MAC, so this variant runs a W5500 — a standalone controller carrying its own MAC, its own PHY, and a hardware TCP/IP stack, talking to the MCU over SPI. The alternative in this class is an ESP32-classic driving an external PHY over RMII, which consumes nine GPIO and runs the network stack on the same cores rendering your effects. Here, the network is somebody else's job.

**Data lines treated like data lines.** Series resistance and a sub-picofarad ESD device per channel, placed on the connector side where transients arrive, chosen so the clamp does not round off WS281x bit timing on long runs.

**DMX where you need it.** Four RS-485 ports on RJ45, each with its own transceiver and its own transient protection, alongside the eight pixel channels.

> **Three things on this board can be killed by field abuse. All three pull out by hand.**
>
> **The fuse.** A mini blade — the same part sold in a variety pack at every gas station, auto parts counter and big-box store in the country. Pulls with fingers, costs pennies. Not a cartridge you order online and wait for.
>
> **The buffer.** A jellybean octal logic IC in a DIP socket. It sits directly behind your wiring, which makes it the part most likely to die and the part most annoying to replace anywhere else. Here it lifts out with a fingernail. And the socket accepts either of two common octal logic families — a strap on pin 1 handles the output-enable behaviour of one and the direction pin of the other — so you fit whichever is in stock. Supply-chain resilience on a fifty-cent line item sounds trivial right up until the next shortage.
>
> **The MCU.** A socketed module. Blow it up, seat another. No hot air, no braid, no scrap board.
>
> Nobody else in this class can claim all three.

And that is what the board area buys. Blade holders, a DIP socket, and terminal clearance cost real estate — there is room to get an iron in, room to pull a fuse without tweezers, room to reach the reset button without unmounting anything, and room at the terminals for heavy wire with ferrules. Compact is easy. Compact *and serviceable* at 30 A is a different problem, and this is the side of it we chose. A channel that dies at eight o'clock on the twenty-third of December should be a fifteen-minute drive, not a three-day wait.

---

## Where It Goes

- **Large distributed displays** — a dozen or more nodes where Wi-Fi contention becomes the limiting factor
- **Permanent commercial and architectural installations** — where the lighting belongs in the building's network documentation
- **Long runs to outbuildings** — an Ethernet drop instead of a wireless prayer; pixel power still runs on its own conductors
- **High frame-rate sACN or Art-Net** — deterministic delivery, no shared-medium contention

---

## How It Compares

*Comparison basis.* The closest peer is the Bong69 8 Port LED Distro — same idea, power and data integrated on one board, eight ports, wired Ethernet, WLED, sold at maker scale. QuinLED's Dig-Quad supports an Ethernet-capable brain board and is the other reference point. Competitor figures are taken from the vendors' own published FAQ and specification pages as of July 2026 and should be re-verified before publication.

Athom's WLED range is deliberately excluded: single-strip and PWM controllers aimed at room-level and audio-reactive use. Different product, different buyer.

| | **NODE Backbone** | **Bong69 8 Port LED Distro** | **QuinLED-Dig-Quad v3** |
|---|---|---|---|
| Output channels | 8 | 8 | 4 |
| Control transport | Wired Ethernet | Wired Ethernet (WT32-ETH01) | Wi-Fi, or Ethernet via brain board |
| Ethernet implementation | W5500 dedicated controller on SPI — own MAC, PHY and hardware TCP/IP | ESP32 internal RMII MAC + external PHY — consumes 9 GPIO | Per brain board |
| Controller power | PoE from the switch | From the pixel supply | From the pixel supply |
| Reachable with pixel supply off | Yes | No | No |
| Pixel input range, one SKU | 5–48 VDC | V4: 12–48 V (5 V support dropped) · V3: 5–24 V (discontinued) | 5–24 VDC |
| Covers 5/12/24/36 V pixels | Yes, one board | No — requires choosing a version | Jumper-selectable up to 24 V; 36 V not supported |
| Input voltage selection | None — nothing to set wrong | Per board version | Jumper; vendor warns wrong setting "will fry the onboard components" |
| Input connector | Enclosed 57 A screw terminal | V4: spade connectors on a stud | Screw terminal |
| Continuous current, standard copper | 30 A | Not published | 15 A at 1 oz (30 A only with paid 2 oz upgrade) |
| Per-channel fuse rating | 7.5 A nominal · 10 A max per output | 5 A (V4) · 4 A hold / 8 A trip polyfuse (V3) | 10 A max recommended |
| Fuses on outputs | 8 — one per channel | 8 — one per channel | 5 fuses across 7 outputs (channels share) |
| Reverse-polarity protection | Active blocking — non-destructive, self-recovering | Not published | Parallel diode with fuse — sacrificial |
| Input transient clamp | Bidirectional TVS across the input | Not published | Not published |
| Data-line ESD protection | Per channel, sub-pF device | Series resistor only (33 Ω) | Not published |
| Power domain separation | 3 pixel domains + isolated network domain | Not published | Single rail |
| DMX-512 / RS-485 output | 4 ports, individually protected | Not published | Not published |
| Level shifter | 8-channel, socketed DIP | Not published | 4-channel, soldered |
| Conformal coating | Yes, applied at the fab | Not offered | Not offered |
| Fuse-status indicator | Per-channel LED | Blue "good fuse" LED per channel | Per board |
| Onboard USB programming | Via the module's own port | Onboard USB-C — required, the ESP is soldered down | Via the module's own port |
| Field-replaceable MCU | Yes — socketed module | No — ESP32-WROOM soldered to the board | Yes — socketed module |
| Fuse replacement | Mini blade — auto parts store, gas station, variety pack | Cartridge in a surface-mount holder — order online | ATO blade — auto parts store |
| Audio-reactive / mic support | DIY — headers fitted, spare GPIO available | DIY — wire an INMP441 to the H1 header (documented) | Analog audio input broken out |
| Temperature sensor support | DIY — headers fitted, spare GPIO available | DIY — add header, DS18B20 and 4.7 kΩ (documented) | Optional onboard footprint |
| Enclosure | Free 3D-printable [NODE Enclosures](../../Node%20Enclosures/), with or without an integrated PSU | None — 3D-print mounts published | None — bare board |
| Board size | 123 × 129 mm — the cost of blade holders, a DIP socket and terminal clearance | ~110 × 70 mm | ~100 × 50 mm |
| Firmware | WLED / ESPHome / ESPixelStick — module-level, not board-level | Same | Same |
| Firmware image | Pre-built Ethernet image supplied | Pre-built image supplied; ESPixelStick needs the vendor hardware profile | Stock WLED builds |
| Ecosystem | New | Established, reviewed, xLights docs | Large, mature, well documented |

*A note on firmware comparisons.* WLED, ESPHome, and ESPixelStick are properties of the ESP32 silicon, not of the carrier board — any of them will run on any of these products. What actually differs is which pre-built image ships, and how much GPIO the board's own hardware has already spent before your channels get any.

**Where the others are the better choice, plainly.** Bong69 ships a proven, well-reviewed Ethernet board with onboard USB-C programming, per-fuse status LEDs, documented audio-reactive and temperature-sensor support, xLights integration notes, published 3D-print mounts, and boards that arrive pre-configured and tested. QuinLED brings a deep peripheral breakout and years of community documentation. Neither ecosystem exists here yet. If you want established products, buy theirs.

**Where NODE Backbone is the better choice.** Everyone in this class can do Ethernet. Almost nobody powers the controller from it. PoE means one cable to the node, no second low-voltage feed into the enclosure, and a controller that stays on the network with the pixel supply dark — the difference between diagnosing a dead zone from your desk and diagnosing it from a ladder. Add one board covering 5/12/24/36 V pixels with every part in the power path well below its rating — no version to pick, an enclosed 57 A terminal instead of exposed lugs, and four levels of protection on separate copper.

**And plainly:** if one controller sits in a garage and works fine on Wi-Fi, buy NODE Mini and save the money. NODE Backbone earns its price at the scale where wireless stops being reliable — a threshold that arrives earlier than most people expect.

---

## Mounting & Enclosure

**No enclosure is included with the board, but three are available.** The [NODE Enclosures](../../Node%20Enclosures/) are free to 3D-print from this repository, or can be bought printed from the store, on their own or bundled with a controller. **NODE Aegis** holds the board alone. **NODE Bastion 350** and **NODE Citadel 600** hold the board together with a Mean Well LRS-350 or LRS-600 supply. All three have a gland wall for power in and eight pixel runs, a sealed lid joint, and printed mounts for an optional 5 V fan.

The board still mounts just as well in whatever the installation already uses: a CG1500, a DIN rail, a weatherproof box, a plywood backer.

What NODE adds instead is **conformal coating, applied at the fabrication facility** with connectors, sockets, fuse clips, and switches masked. Competing boards in this class ship uncoated. A coated board in a vented enclosure tolerates condensation and humidity in a way a bare board does not, which matters for the seasonal outdoor installs this was built for.

Four corner mounting holes are provided. *Hole spacing and a downloadable mount STL: to be published at first article.*

**Enclosure note specific to this variant:** the Ethernet jack requires clearance and cable strain relief at the enclosure wall. Plan the entry before drilling. The NODE Enclosures leave the Ethernet hole undrilled for this reason; drill it for an M25 gland, or whatever size your cable and jack need.

---

## Build & Assurance

- **Fabrication** — 4-layer, 1.6 mm, high-T<sub>g</sub> substrate, ENIG finish, epoxy-filled and capped vias, IPC Class 2 workmanship
- **Assembly** — professional SMT assembly, flying-probe electrical test on 100% of boards
- **Traceability** — 2D barcode serial on every board; UL-recognized substrate marking
- **Coating** — conformal coating applied at the fab, with connectors, sockets, fuse clips, and switches masked
- **Design review** — every net verified against manufacturer datasheets; schematics independently reviewed by two automated analysis passes with human verification of every finding

---

## Ordering

| Item | Detail |
|---|---|
| Model | NODE Backbone |
| Configuration | Assembled, tested, conformal coated |
| Included | Controller board, level shifter installed, fuses installed |
| Not included | Enclosure (free to print or sold separately, see [NODE Enclosures](../../Node%20Enclosures/)), Waveshare ESP32-S3-ETH-POE module, 3-pin plug connectors, blade fuses beyond those fitted, pixel supply, Ethernet cable |
| Availability | Pre-release. The present build is a validation run — first-article hardware for bring-up, characterisation and field trial. |
| Price | TBD |
| Lead time | TBD |
| Warranty | TBD |

---
---

# NODE Backbone — Technical Specification

**Document rev:** 3.0 · **Board rev:** V1a · **Date:** 2026-09-01

> **Components are specified by function and rating.** Specific manufacturers and part
> numbers are selected at build time and may change with availability; every substitution
> is held to the ratings stated here.

## 1. Power Architecture

Three pixel-side domains plus an independent network-powered logic domain:

| Domain | Boundary | What it carries |
|---|---|---|
| **Input (unprotected)** | Screw terminal → ideal-diode stage | Raw supply. Assumed hostile. Transient clamp sits across this node. |
| **Clean (protected)** | Ideal-diode output → main fuse | Reverse-blocked, surge-clamped. Bulk capacitance lives here. |
| **Distribution bus (fused)** | Main fuse → 8 channel fuses | Every output taps this bus through its own fuse. |
| **Logic (network-powered)** | PoE module 5 V output → buffer and indicators | Independent of pixel supply state. Ground domain joined at one defined point. |

## 2. Pixel Input & Protection

| Parameter | Value | Notes |
|---|---|---|
| Pixel input voltage range | 5 – 48 VDC | 36 V nominal, 48 V absolute maximum |
| Input connector | Enclosed 2-pole screw terminal | 57 A / 10 mm² rated; 30 A design maximum = 53% of rating |
| Maximum continuous current | 30 A | At standard 1 oz outer copper — no copper upgrade required |
| Main fuse | 30 A mini blade, user-replaceable | Holder rated 30 A / 500 V |
| Reverse-polarity protection | Ideal-diode controller driving a high-side N-channel pass FET | FET held off under reverse input; no current path to load; non-sacrificial and self-recovering |
| Pass element | 80 V N-channel MOSFET, low milliohm R<sub>DS(on)</sub> | Rated above the input clamp voltage, not below it; current rating several times the 30 A design load |
| Input transient clamp | Bidirectional TVS, 1500 W, 48 V standoff | Conducts in neither direction at rated input; polarity-independent |
| Bulk capacitance | 2 × 1000 µF, 63 V | On the clean rail, downstream of the ideal diode |
| Ideal-diode support | 100 V charge-pump capacitor, 80 V hold-up capacitor | Per the controller's reference design |
| Polarity indication | Anti-parallel green/red LED pair | Green = correct, red = reversed; shared limit resistor sized for the full input range |

**Voltage headroom summary: 36 V nominal, 48 V absolute maximum.** Every component in the power path is rated **63 V or above**; every semiconductor is **60 V or above**.

**Derating against input voltage.** Utilization of each component's own rating. **5 V, 12 V and 24 V are the mainstream pixel voltages** and are shown in bold:

| Component | Rating | **5 V** | **12 V** | **24 V** | 36 V | 48 V |
|---|---|---|---|---|---|---|
| Bulk input capacitors | 63 V | **8 %** | **19 %** | **38 %** | 57 % | 76 % |
| Channel output caps | 80 V | **6 %** | **15 %** | **30 %** | 45 % | 60 % |
| Ideal-diode hold-up | 80 V | **6 %** | **15 %** | **30 %** | 45 % | 60 % |
| HV-plane ceramics | 100 V | **5 %** | **12 %** | **24 %** | 36 % | 48 % |
| Ideal-diode controller | 65 V | **8 %** | **18 %** | **37 %** | 55 % | 74 % |
| Pass MOSFET V<sub>DS</sub> | 80 V | **6 %** | **15 %** | **30 %** | 45 % | 60 % |

At the **36 V nominal** rating no part on the plane exceeds 60 % of its own limit. At the **48 V absolute maximum** nothing exceeds 80 %. On the 5 V, 12 V and 24 V strips that carry the overwhelming majority of installations, the entire plane runs under 40 %.

> On this board, "power path" means *pixel* power path. The logic rail is a separate story — see Section 3.

## 3. Logic Rail

| Parameter | Value | Notes |
|---|---|---|
| 5 V source | Waveshare ESP32-S3-ETH-POE module | **No onboard buck converter on this variant** |
| Supply path | Module 5 V output → buffer, indicators | Independent of the pixel input rail |
| 5 V rail clamp | Unidirectional TVS, 6 V standoff | Protects the PoE-derived rail |
| Grounding | Module ground domain merged to board ground at a single defined point | Isolation handled explicitly in layout |
| Behavior with pixel supply off | Controller remains powered and network-reachable | Configuration and diagnostics available without strip power |

## 4. Outputs

| Parameter | Value | Notes |
|---|---|---|
| Channels | 8 | Independent, individually fused — no shared fuses |
| Output connector | 3-pole pluggable terminal, per channel | V+ / DATA / GND; 12 A rated → 63% at the 7.5 A fitted fuse, 83% at the 10 A maximum |
| Per-channel fuse | 7.5 A mini blade fitted, 10 A maximum | 25% of holder rating at 7.5 A, 33% at 10 A; user-replaceable |
| Level translation | Octal logic buffer, DIP-20 socket | Accepts either of two common octal families; 3.3 V drive against a 2.0 V V<sub>IH</sub> = 1.3 V margin |
| Data series resistance | 330 Ω, axial through-hole, per channel | Limits fault current back into the buffer |
| Data ESD protection | Sub-picofarad ESD device, per channel, connector side | 0.4–0.55 pF junction capacitance; RC ≈ 181 ps — no measurable effect on WS281x bit timing |
| Data drive current | ≈ 4 mA per channel | 67% of the ±6 mA buffer rating |
| Buffer supply current | ≈ 45 mA total | 64% of the 70 mA device maximum |
| Per-channel decoupling | 47 µF electrolytic 80 V + 100 nF ceramic 100 V | Local to each output connector |
| Channel activity indication | One LED per channel | Data activity on that channel |
| Fuse-status indication | One LED per channel, fed from the post-fuse node | Lit = that channel's fuse is intact and the bus is live |

### 4b. DMX-512 / RS-485 Output

| Parameter | Value | Notes |
|---|---|---|
| Ports | 4 | RJ45, T568B pairing |
| Transceivers | One RS-485 transceiver per port | Driver enables tied to a shared enable net; transmit data shared across all four |
| Receive | Port 1 only | The remaining three ports are transmit-only by design |
| Port protection | TVS array on the connector-side net, plus series resistance per line | Clamp sits ahead of the series limiting, in that order |

## 5. MCU, Network & Firmware

| Parameter | Value |
|---|---|
| Module | Waveshare ESP32-S3-ETH-POE *(not included)* |
| Mounting | Socketed — removable without desoldering |
| Network interface | Wired 10/100 Ethernet, W5500 controller on SPI |
| Ethernet architecture | Dedicated MAC + PHY + hardware TCP/IP offload; MCU cores not used for the stack |
| Power over Ethernet | IEEE 802.3af compliant, via the module's PoE daughterboard |
| Wireless | Wi-Fi available on module; wired Ethernet is the intended control path |
| Firmware | WLED — pre-built Ethernet image supplied (W5500 SPI configuration) |
| Supported LED protocols | WS2811, WS2812/B, WS2813, WS2815, WS2816, SK6812/RGBW, TM1814, and other single-wire families supported by WLED |
| Control protocols | Per WLED: E1.31/sACN, Art-Net, DDP, MQTT, HTTP/JSON API. DMX-512 over the onboard RS-485 ports |
| Additional I/O | Spare module GPIO broken out on fitted headers for I²C and SPI peripherals, plus 3.3 V / 5 V / GND / TX / RX — no LED channels sacrificed |
| GPIO restriction | GPIO33–GPIO37 are consumed by the module's octal PSRAM and are unavailable; channel assignments avoid these pins by design |

> **Integrator note:** the module is an 802.3af powered device. Confirm the total PoE budget on your switch before populating it with many nodes.

## 6. Physical

| Parameter | Value |
|---|---|
| PCB dimensions | 123 × 129 mm |
| PCB thickness | 1.6 mm |
| Layer count | 4 — signal / ground plane / split power plane / signal |
| Copper weight | 1 oz outer, 1 oz inner |
| Substrate | High-T<sub>g</sub> 155 °C |
| Surface finish | ENIG, 1 µ" gold |
| Via treatment | Epoxy filled and capped |
| Soldermask | Blue |
| Mounting | 4 × corner mounting holes, 3 mm |
| Mounting hole spacing | 107.9 × 103.8 mm |
| Enclosure | Free 3D-printable [NODE Enclosures](../../Node%20Enclosures/), with or without an integrated PSU |
| Net weight | TBD — measure at first article |
| Conformal coating | Applied at the fab; connectors, sockets, fuse clips, and switches masked |

## 7. Environmental & Compliance

| Parameter | Value |
|---|---|
| Operating temperature | −20 °C to +60 °C *(design target; not qualification tested)* |
| Substrate rating | UL-recognized, JLC-1 marking |
| RoHS | Compliant |
| Workmanship | IPC Class 2 |
| Electrical test | Flying-probe, 100% of boards |
| Traceability | 2D barcode serial number, per board |

## 8. Design Notes & Accepted Limitations

Stated plainly rather than buried:

- **Not automotive qualified.** Protection targets transients credible in a residential or light-commercial installation. Not tested to ISO 7637 load-dump profiles; not intended for vehicle use.
- **Worst-case clamp coordination.** At the TVS datasheet maximum clamping voltage under a full rated pulse, the voltage presented to downstream components exceeds their ratings. That condition requires a pulse energy source which does not exist in a mains-fed low-voltage installation, and is accepted as non-credible for the intended deployment. At realistic clamp currents the entire downstream chain retains margin.
- **Over-voltage beyond specification is not survivable.** A supply above the rated input range will conduct the input TVS and open the main fuse. Sacrificial by design — the board is protected, the TVS and fuse are consumables.
- **No onboard 5 V regulator.** Logic power comes exclusively from the module. An unpowered Ethernet drop means an unpowered controller regardless of pixel supply state.
- **PoE budget is the installer's responsibility.** Node count per switch is bounded by the switch's total PoE power budget, not by this board.
- **Load capability.** Pixel power comes directly from the distribution bus; total system current is bounded by the 30 A main fuse and the user's supply.

---

*Wateefy Electronics · NODE Backbone · Specifications subject to change.*
*Wateefy Electronics · NODE Backbone · Specifications subject to change.*

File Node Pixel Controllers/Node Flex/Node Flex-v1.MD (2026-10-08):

# NODE Flex
### 8-Channel Addressable LED Controller · Universal Module Carrier

*Wateefy Electronics*

---

> **One board. The Swiss Army knife of pixel controllers.**

*[Hero image: populated NODE Flex board with DevKit installed, three-quarter view]*

---

## At a Glance

- **8 independent output channels** — WS281x / SK6812 / TM1814 family, 5 V level-shifted drive
- **Any ESP32 DevKit on 0.9″ or 1.0″ row spacing** — both spacings on the board, up to 22 positions per row, jumper-mapped to the outputs
- **5–48 VDC input, no voltage jumper** — **36 V nominal, 48 V maximum**; nothing to set wrong, ever
- **30 A through the board at standard copper** — not a paid upgrade
- **Three isolated power domains** — dirty input, clean protected power, fused distribution bus
- **A fuse on every single output** — eight channels, eight fuses, no sharing
- **Non-destructive reverse-polarity protection** — nothing is consumed when someone wires it backwards

**123 × 138 mm** · 4-layer · ENIG · conformal coated

---

## Why This Exists

Every ESP32 DevKit has a different pinout. Every controller board is hard-wired to exactly one of them. So the board you bought last year is scrap when that module goes end-of-life, and the four dev boards in your parts drawer are useless because none of them match the footprint someone else chose.

NODE Flex breaks that dependency by defining compatibility as **geometry rather than a part number**. The board carries both of the common DevKit row spacings — 0.9 inch and 1.0 inch — with up to 22 positions in each row. Module length does not matter: a 2×15 or 2×19 board seats in the same sockets and simply leaves positions empty. A jumper field then decides which module pin drives which output channel.

The practical result is that the compatibility list cannot go stale. If a module lands on 0.9″ or 1.0″ centres, it fits — including modules that do not exist yet. When your favourite DevKit is discontinued, and it will be, you seat a different one and keep going. Same board, same protection, same firmware.

For anyone maintaining an installed base across mixed hardware, this is the SKU that ends the inventory problem.

---

## The Architecture: Three Power Domains

Flexibility lives in the MCU interface. Nothing upstream of it was softened to get there.

Most controllers have one power rail. Input voltage lands on a terminal and it is the same copper that reaches your strips. Whatever arrives — spike, reverse polarity, sag, transient — arrives everywhere at once.

**NODE splits power into three separate domains on their own copper planes:**

**1 · Dirty power in.** The input terminal accepts whatever the supply, the wiring, and the person doing the wiring hand it. This domain is assumed hostile, isolated to the smallest region of the board possible, and nothing downstream touches it directly.

**2 · Clean power.** Between dirty and clean sits the protection stage: bidirectional transient clamping and an *active* reverse-polarity blocker. Reverse the supply and the pass element never turns on — no current path to the rest of the board, nothing sacrificed, red indicator tells you why. Correct the wiring and it recovers on its own.

**3 · The protected bus.** Clean power passes the main fuse to become the distribution bus. Each of the eight output channels taps that bus through its own fuse. A fault on run six opens one fuse and the other seven never notice.

> ### BEEFCAKE.
> *The pass element is a 205 A MOSFET on a 30 A board. It will never be the thing that fails.*

**Decoupling where the current actually is.** Two thousand microfarads of bulk sits on the protected bus, and another forty-seven at *every single output connector*. The distribution is the point: one reservoir at the input cannot cover the harness inductance of eight separate output runs no matter how large it is. When a full-white frame lands on all eight channels at once, each channel draws from its own reserve sitting centimetres from its terminal.

Four levels between the screw terminal and your pixels — clamp, active block, main fuse, channel fuse — each on its own copper. That is why this is a four-layer board with a split inner power plane rather than two layers and one pour.

**Nothing in that power path is rated below 63 V — and every semiconductor in it is 60 V or above — against a 48 V maximum input.** Nothing in the chain runs near its limit.

**At maximum rated input, no component in the power path operates above 72% of its rating.** The pass MOSFET sits at 60%, the ideal-diode controller at 55%, the regulator at 45%. It is not a number anyone else in this class publishes, and it is the reason to believe the rest of this page.

---

## What Else You Actually Get

**Defined-state inputs.** Because a channel's jumper may legitimately be left unset, every buffer input carries a pull-down resistor. An unconfigured channel sits at a known logic low instead of floating and driving whatever it feels like — which on a strip full of pixels means darkness rather than noise. This is the detail that separates a real universal carrier from a breakout board with headers.

**Data lines treated like data lines.** Each output runs through a series resistor and a sub-picofarad ESD device placed on the *connector* side, where transients actually arrive. The low-capacitance part was chosen deliberately: a fat protection diode on a data line rounds off WS281x bit timing and produces a controller that works on the bench and sparkles on a 40-foot run.

**Three things on this board can be killed by field abuse. All three pull out by hand.**

**The fuse.** A mini blade — the same part sold in a variety pack at every gas station, auto parts counter and big-box store in the country. Pulls with fingers, costs pennies. Not a cartridge you order online and wait for.

**The buffer.** A jellybean octal logic IC in a DIP socket. It sits directly behind your wiring, which makes it the part most likely to die and the part most annoying to replace anywhere else. Here it lifts out with a fingernail. And the socket accepts **either a '541 or a '245** — the strap that sets pin 1 handles the 541's active-low output enable and the 245's direction pin, so you fit whichever is in stock. Supply-chain resilience on a fifty-cent line item sounds trivial right up until the next shortage.

**The MCU.** A socketed module. Blow it up, seat another. No hot air, no braid, no scrap board.

Nobody else in this class can claim all three.

**And that is what the board area buys.** Blade holders, a DIP socket, and terminal clearance cost real estate — there is room to get an iron in, room to pull a fuse without tweezers, room to reach the reset button without unmounting anything, and room at the terminals for heavy wire with ferrules. Compact is easy. Compact *and* serviceable at 30 A is a different problem, and this is the side of it we chose. A channel that dies at eight o'clock on the twenty-third of December should be a fifteen-minute drive, not a three-day wait.

**Serviceable by design.** The level shifter sits in a DIP socket. The DevKit sits in headers. Fuses pull by hand. Through-hole parts dominate the power section on purpose — this board is meant to be repaired, not replaced.

---

## Where It Goes

- **Mixed-hardware installations** — one controller SKU across a fleet built from whatever modules were available that year
- **Development and evaluation** — swap modules against a known-good, fully protected carrier
- **Long-life deployments** — the board outlives the module generation it was built around
- **Distributed whole-property displays** — one node per zone, eight runs each, scale by adding nodes

---

## How It Compares

**Comparison basis.** The closest peer is the Bong69 8 Port LED Distro — same idea, power and data integrated on one board, eight ports, WLED, sold at maker scale. QuinLED's Dig-Quad is the other reference point. Competitor figures are taken from the vendors' own published FAQ and specification pages as of July 2026 and should be re-verified before publication.

*Athom's WLED range is deliberately excluded: single-strip and PWM controllers aimed at room-level and audio-reactive use. Different product, different buyer.*

| | **NODE Flex** | Bong69 8 Port LED Distro | QuinLED-Dig-Quad v3 |
|---|---|---|---|
| Output channels | 8 | 8 | 4 |
| **MCU compatibility** | **Any DevKit on 0.9″ or 1.0″ row spacing, any length up to 22 positions** | Fixed — WT32-ETH01 integrated | Fixed footprint — QuinLED-ESP32 or D1 Mini 32 |
| Survives module obsolescence | Yes — jumper a different DevKit | No — board is the module | No |
| **Input range, one SKU** | **5–48 VDC** | V4: 12–48 V (**5 V support dropped**) · V3: 5–24 V (**discontinued**) | 5–24 VDC |
| Covers 5/12/24/36/48 V pixels | Yes, one board | 12–48 V only — 5 V support dropped in V4 | Jumper-selectable up to 24 V; 36 V and 48 V not supported |
| Input voltage selection | None — nothing to set wrong | Per board version | Jumper; vendor warns wrong setting *"will fry the onboard components"* |
| Input connector | Enclosed 57 A screw terminal | V4: spade connectors on a stud | Screw terminal |
| Continuous current, standard copper | 30 A | Not published | 15 A at 1 oz (30 A only with paid 2 oz upgrade) |
| Per-channel fuse rating | 7.5 A nominal · 10 A max per output | 5 A (V4) · 4 A hold / 8 A trip polyfuse (V3) | 10 A max recommended |
| Fuses on outputs | 8 — one per channel | 8 — one per channel | 5 fuses across 7 outputs (channels share) |
| Reverse-polarity protection | Active blocking — non-destructive, self-recovering | Not published | Parallel diode with fuse — sacrificial |
| Input transient clamp | Bidirectional TVS across the input | Not published | Not published |
| Data-line ESD protection | Per channel, sub-pF device | Series resistor only (33 Ω) | Not published |
| Power domain separation | 3 domains: dirty in / clean / fused bus | Not published | Single rail |
| Unconfigured input handling | Pull-down on all 8 buffer inputs | n/a — fixed pinout | n/a — fixed pinout |
| Level shifter | 8-channel, socketed DIP | Not published | 4-channel, soldered |
| Conformal coating | Yes | Not offered | Not offered |
| Fuse-status indicator | Channel activity LED | **Blue "good fuse" LED per channel** | Per board |
| Onboard USB programming | Via the module's own port | Onboard USB-C — required, the ESP is soldered down | Via the module's own port |
| **Field-replaceable MCU** | **Yes — socketed module** | **No — ESP32-WROOM soldered to the board** | Yes — socketed module |
| Fuse replacement | Mini blade — auto parts store, gas station, variety pack | Cartridge in a surface-mount holder — order online | ATO blade — auto parts store |
| Audio-reactive / mic support | DIY — headers fitted, spare GPIO available | DIY — wire an INMP441 to the H1 header (documented) | **Analog audio input broken out** |
| Temperature sensor support | DIY — headers fitted, spare GPIO available | DIY — add header, DS18B20 and 4.7 kΩ (documented) | **Optional onboard footprint** |
| Enclosure | Free 3D-printable [NODE Enclosures](../../Node%20Enclosures/), with or without an integrated PSU | None — 3D-print mounts published | None — bare board |
| Board size | 123 × 138 mm — *the cost of blade holders, a DIP socket and terminal clearance* | ~110 × 70 mm | ~100 × 50 mm |
| Firmware | WLED / ESPHome / ESPixelStick — module-level, not board-level | Same | Same |
| Firmware image | Pre-built image supplied per module | Pre-built image supplied; ESPixelStick needs the vendor hardware profile | Stock WLED builds |
| Ecosystem | New | **Established, reviewed, xLights docs** | **Large, mature, well documented** |

**A note on firmware comparisons.** WLED, ESPHome, and ESPixelStick are properties of the ESP32 silicon, not of the carrier board — any of them will run on any of these products. What actually differs is which pre-built image ships, and how much GPIO the board's own hardware has already spent before your channels get any.

**Where the others are the better choice, plainly.** Bong69 ships a proven, well-reviewed board with onboard USB-C programming, per-fuse status LEDs, documented audio-reactive and temperature-sensor support, xLights integration notes, published 3D-print mounts, and boards that arrive pre-configured and tested. QuinLED brings a deep peripheral breakout and years of community documentation. Neither ecosystem exists here yet. If you want established products, buy theirs.

**Where NODE Flex is the better choice.** Every competing board *is* its module — when that ESP32 variant goes end-of-life, the board goes with it. NODE Flex is a carrier: the module is a consumable, the protected power section is the product. Add one board covering 5/12/24/36/48 V pixels with every part in the power path rated at least 1.3× the maximum input — no version to pick, eight fuses for eight channels, an enclosed 57 A terminal instead of exposed lugs, and four levels of protection on separate copper.

**The honest summary:** buy Bong69 or QuinLED if you want the mature ecosystem and never intend to change modules. Buy Flex if you have four different DevKits in a drawer, or if you expect to still be maintaining this installation after the current module generation is gone.

---

## Ordering

| Item | Detail |
|---|---|
| Model | NODE Flex (V1a) |
| Configuration | Assembled, tested, conformal coated |
| Included | Controller board, level shifter installed, fuses installed |
| Not included | Enclosure (free to print or sold separately, see [NODE Enclosures](../../Node%20Enclosures/)), ESP32 DevKit module, jumper shunts, 3-pin plug connectors, blade fuses beyond those fitted, power supply |
| Availability | **Not currently offered for sale.** The present build is a validation run — first-article hardware for bring-up, characterisation and field trial. |
| Sale status | Planned for the next revision |
| Price | *TBD* |
| Lead time | *TBD* |
| Warranty | *TBD* |

---
---

# NODE Flex V1a — Technical Specification

**Document rev:** 2.1 · **Board rev:** V1a · **Date:** 2026-08-06

---

---
---

# NODE Flex V1a — Variant Specification

**Document rev:** 3.0 · **Board rev:** V1a · **Date:** 2026-08-06

*Power architecture, input protection, outputs, environmental and build data are common to the NODE family and are documented in the **NODE Platform Hardware Reference**. This supplement covers only what is specific to NODE Flex.*

---

## 1. 5 V Logic Rail

| Parameter | Value | Notes |
|---|---|---|
| Regulator | LMR38020SDDAR synchronous buck | HSOIC-8 with PowerPAD, 12 thermal vias |
| Absolute maximum input | 85 V | 68% utilization at worst-case TVS clamp |
| Switching frequency | 400 kHz | Set by 64.9 kΩ RT resistor |
| Output voltage | 5.115 V | 100 kΩ / 24.3 kΩ divider, 1.0 V reference |
| Output current capability | 2 A | Actual load ≈ 0.5 A → 25% utilization |
| Inductor | 15 µH, 3.0 A saturation, 2.5 A RMS | 79% of saturation rating at full 2 A load |
| Output capacitance | 3 × 22 µF ceramic, 16 V | Per regulator datasheet recommendation |
| Module bulk capacitance | 100 µF, 25 V | Local reserve for Wi-Fi transmit transients |
| Rail bypass | 100 nF ceramic, 50 V | Behind regulation — HV plane rating does not apply |
| Input capacitance | 47 µF electrolytic 80 V + 4.7 µF + 100 nF, ceramics 100 V X7R | Rated for the full input range with derating headroom |
| 5 V rail clamp | SMAJ6.0A TVS | 6 V standoff vs 5.24 V worst-case rail = 87% |
| Minimum on-time margin | 2.0× at 48 V input | No frequency foldback anywhere in the input range |
| Manual reset | Momentary switch to regulator enable | 10 kΩ pull-up to distribution bus |

## 2. MCU Interface & Firmware

| Parameter | Value |
|---|---|
| Module support | Any ESP32-family DevKit on a supported row spacing (module not included) |
| Supported row spacings | **0.9″ (22.86 mm)** and **1.0″ (25.4 mm)** — both provided on the board |
| Socket rows | 2.54 mm pitch, up to 22 positions per row |
| Module length | Not constrained — shorter modules (2×15, 2×19) seat in the same rows, leaving positions unused |
| Channel assignment | Jumper header maps module GPIO to each of the 8 buffer inputs |
| Unconfigured channels | Held low by pull-down — no floating inputs |
| Buffer enable | Strap-selectable buffer output enable |
| Firmware | WLED — pre-built image supplied, configured for the fitted module's GPIO map |
| Supported LED protocols | WS2811, WS2812/B, WS2813, WS2815, WS2816, SK6812/RGBW, TM1814, and other single-wire families supported by WLED |
| Connectivity | Per installed module — Wi-Fi 2.4 GHz, or wired Ethernet / PoE-Ethernet where the DevKit provides it (e.g. WT32-ETH01) |
| Verified Ethernet DevKits | WT32-ETH01, WT32-ETH01-EVO and WT32-ETH02-PLUS all sit on 0.9″ (22.86 mm) centres and seat directly, leaving one free socket row per side |
| Known non-fitting modules | Olimex and LilyGo boards use non-standard row spacings and will **not** seat directly — they require an adapter or hand-wiring. Check your module's row centres against 0.9″ / 1.0″ before ordering |
| Control protocols | Per WLED: E1.31/sACN, Art-Net, DDP, MQTT, HTTP/JSON API |
| Additional I/O | Spare module GPIO broken out on fitted headers for I²C and SPI peripherals, plus 3.3 V / 5 V / GND / TX / RX. Availability depends on the fitted DevKit |

**Integrator note:** confirm that the GPIO assigned to a channel is not a boot-strapping pin on your specific module, and is free of flash or PSRAM duties. Pin restrictions vary by module and remain the integrator's responsibility.

## 3. Physical

| Parameter | Value |
|---|---|
| PCB dimensions | 123 × 138 mm |
| PCB thickness | 1.6 mm |
| Layer count | 4 — signal / ground plane / split power plane / signal |
| Copper weight | 1 oz outer, 1 oz inner |
| Substrate | Nan Ya NP-155F, T<sub>g</sub> 155 °C |
| Surface finish | ENIG, 1 µ" gold |
| Via treatment | Epoxy filled and capped |
| Soldermask | Blue |
| Mounting | 4 × corner mounting holes, 3 mm |
| Mounting hole spacing | 107.9 × 103.8 mm |
| Enclosure | [NODE Enclosures](../../Node%20Enclosures/): Aegis (board only), Bastion 350, Citadel 600 (board + PSU) |
| Net weight | *TBD — measure at first article* |
| Conformal coating | Applied after assembly; connectors, sockets, fuse clips, and switches masked |

## 4. Deltas from the Platform Reference

| Item | This variant |
|---|---|
| Input rail | Single rail — powers both pixels and onboard logic |
| Logic supply | Onboard LMR38020 synchronous buck (see §1) |
| Power domains | Three, per the Platform Reference |
| Buffer input pull-downs | 10 kΩ to ground on all 8 inputs — defines logic low when a channel jumper is not fitted; 330 µA sink at logic high |

## 5. Design Notes & Accepted Limitations

Stated plainly rather than buried:

- **Not automotive qualified.** Protection targets transients credible in a residential or light-commercial installation. Not tested to ISO 7637 load-dump profiles; not intended for vehicle use.
- **Worst-case clamp coordination.** At the TVS datasheet maximum clamping voltage under a full 1500 W pulse, the voltage presented to the pass MOSFET and bulk capacitors exceeds their ratings. That condition requires a pulse energy source which does not exist in a mains-fed low-voltage installation, and is accepted as non-credible for the intended deployment. At realistic clamp currents the entire downstream chain retains margin.
- **Over-voltage beyond specification is not survivable.** A supply above the rated input range will conduct the input TVS and open the main fuse. Sacrificial *by design* — the board is protected, the TVS and fuse are consumables.
- **Module compatibility is defined mechanically, and validated electrically by the integrator.** Any DevKit on 0.9″ or 1.0″ row spacing will seat. Whether a given GPIO on that module can drive an output channel is a separate question: strapping pins, flash and PSRAM duties, and input-only pins differ by module and must be checked against the module's own documentation before assigning channels. Olimex and LilyGo boards use non-standard row spacings and will not drop straight in — they need an adapter or hand-wiring to reach the socket rows.
- **Load capability.** The 5 V rail powers onboard logic and indicators only. Pixel power comes directly from the distribution bus; total system current is bounded by the 30 A main fuse and the user's supply.

---

*Wateefy Electronics · NODE Flex · Specifications subject to change.*

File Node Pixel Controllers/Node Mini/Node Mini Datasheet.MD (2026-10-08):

# NODE Mini

### 8-Channel Addressable LED Controller · Mini Node

*Wateefy Electronics*

> **The smallest node in the network. None of the compromises.**

---

## At a Glance

- **8 independent output channels** — WS281x / SK6812 / TM1814 family, 5 V level-shifted drive
- **5–48 VDC input, no jumpers** — the same board runs 5/12/24/36 V systems with nothing to set wrong
- **30 A through the board at standard copper** — not a paid upgrade
- **Three isolated power domains** — dirty input, clean protected power, fused distribution bus
- **A fuse on every single output** — eight channels, eight fuses, no sharing
- **Non-destructive reverse-polarity protection** — nothing is consumed when someone wires it backwards
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

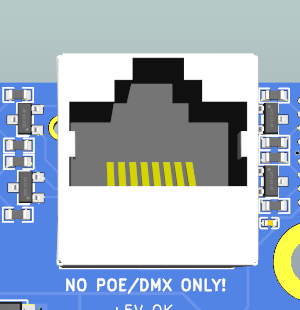
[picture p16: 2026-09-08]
images/DMX_jack.png

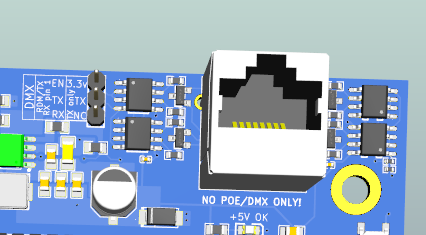
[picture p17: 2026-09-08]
images/Node_Flex_DMX.png

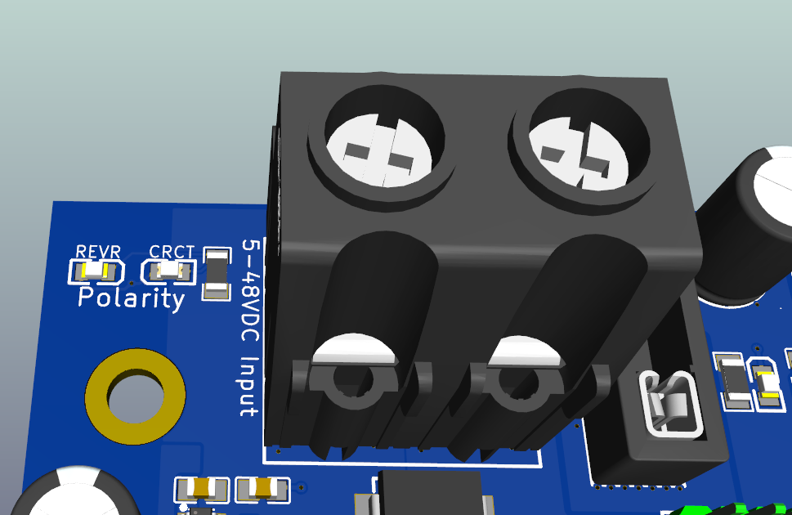
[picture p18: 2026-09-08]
images/Input_Terminal_top.png

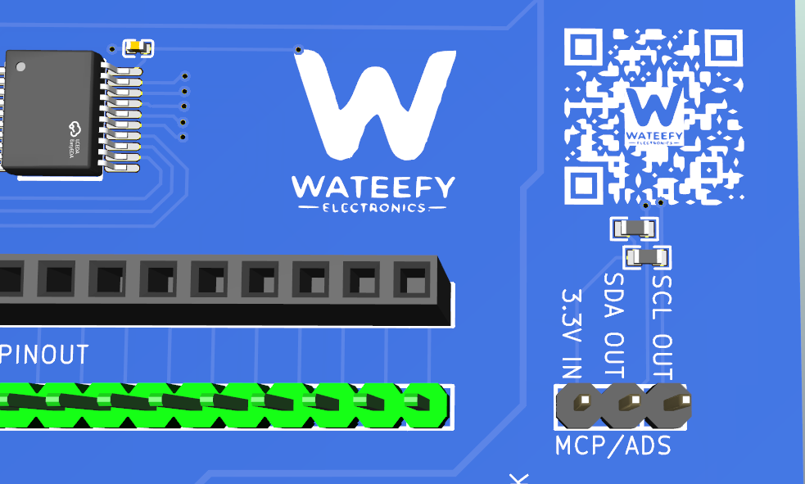
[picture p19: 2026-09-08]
images/flex_mcp_ads_header_image1.png

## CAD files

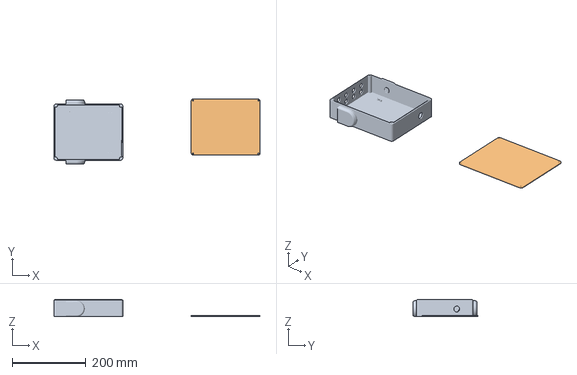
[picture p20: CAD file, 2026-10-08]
Node Enclosures/Aegis/NODE-Aegis-Enclosure.3mf
559.3 x 177.2 x 47.4 mm
Assembly
ENCLOSURE LID

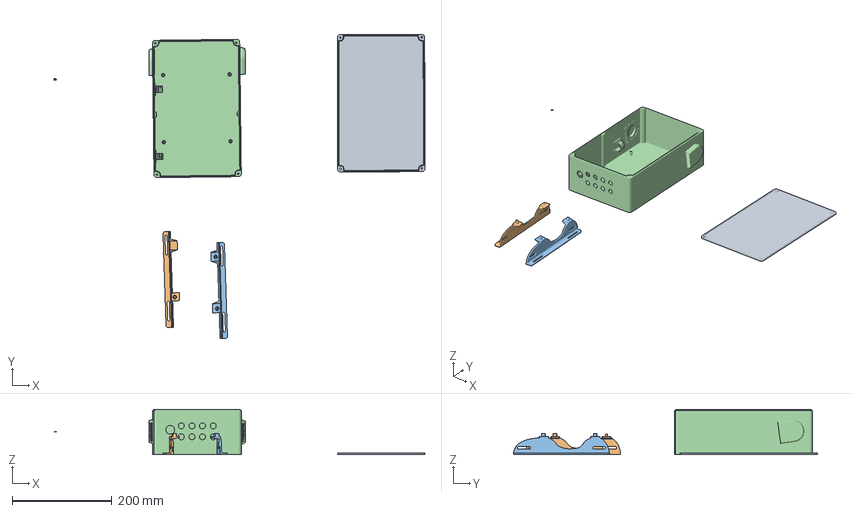
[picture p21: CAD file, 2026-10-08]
Node Enclosures/Bastion 350/NODE-Bastion-350-Enclosure.3mf
742.8 x 609.3 x 90.5 mm
LID
Assembly x 3

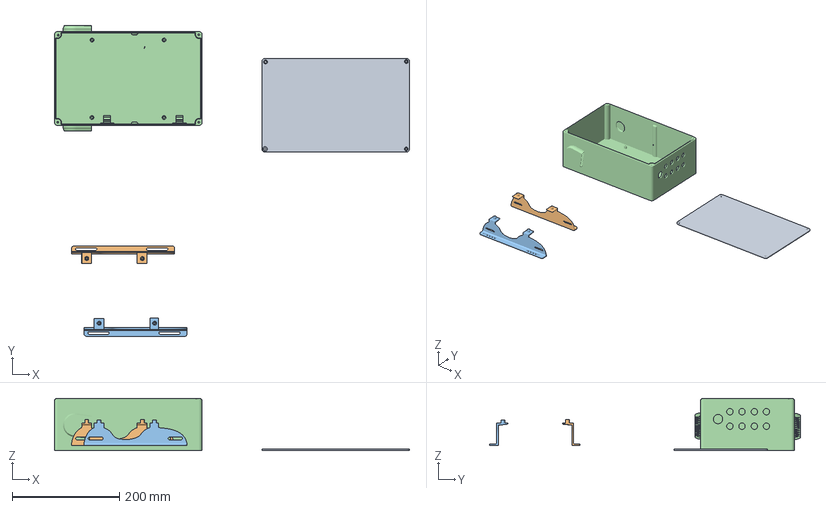
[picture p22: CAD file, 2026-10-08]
Node Enclosures/Citadel 600/NODE-Citadel-600-Enclosure.3mf
661.3 x 578.6 x 97.5 mm
Enclosure_LID
Assembly x 3

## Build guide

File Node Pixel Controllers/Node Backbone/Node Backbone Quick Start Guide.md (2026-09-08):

# NODE Backbone — Quick Start Guide
 
*Node Backbone, V1b*
 
Welcome to your NODE Backbone! Backbone is the PoE/Ethernet variant — your controller is powered and network-reachable straight off your Ethernet switch, separate from your pixel power supply. DMX, ADС/fuse-status monitoring, and the STEMMA QT I²C port are all hardwired for you — no jumpering required. This guide gets you from box to lit-up pixels. For full specs and troubleshooting, see the **NODE Backbone Full Guide**.
 
## What you'll need
 
- NODE Backbone board
- Waveshare ESP32-S3-ETH-POE module — unless you bought the kit
- TI level shifter, SN74AHCT541N or SN74AHCT245N — unless you bought the kit
- Terminal blocks: 3-pin, 5.08mm, Phoenix-style PCB screw terminal — unless you bought the kit
- Fuses: 30A standard blade (main input), 7.5A standard blade (per-channel output) — unless you bought the kit
- 5–48 VDC power supply sized for your pixel run (this powers your **pixels only** — see Step 3 for the controller's own power)
- **Required:** an IEEE 802.3af-compliant Power over Ethernet (PoE) network switch or power injector, plus an Ethernet cable — this is the only way to power the controller (see Step 3)
- WS281x/SK6812/TM1814-style addressable LED strips or fixtures
- Small Phillips or flathead screwdriver
No jumper wires needed on this board — DMX, the fuse-status/voltage monitor, and the STEMMA QT port are all hardwired.
 
Node Backbone full board overview
 
## Safety first — read this before wiring anything
 
- **This board is not automotive-qualified.** It's designed for residential and light-commercial installs — not vehicles, not industrial equipment.
- **Never connect or disconnect wiring with power applied.** Turn off and unplug your power supply first.
- **Watch your polarity on the input terminal.** It's best practice to always double-check Vin and GND before powering up. The board has an ideal-diode circuit to protect against damage from a reversed input, and a Polarity LED that shows green (correct) or red (reversed) so you know at a glance.
- **Match your fuses to your load.** Don't upsize fuses beyond what's printed on the silkscreen — the board's rated limits are there for a reason.
- **Don't confuse the DMX jack with the Ethernet/PoE jack.** The DMX port is RJ45-shaped but carries DMX/RS-485 signaling, not Ethernet — never plug it into a network switch, PoE injector, or a cable meant for your Ethernet connection. DMX gear only.
- **An unpowered Ethernet drop means an unpowered controller.** There's no fallback power path on this board — if your Ethernet/PoE connection drops, the controller goes down even if your pixel supply is still on.
- **This board must be powered by an IEEE 802.3af-compliant PoE switch or injector.** There is no other way to power the controller — the pixel input terminal (Step 1) does not power it.
## Step 1 — Wire your power input
 
Find the terminal block marked **"5-48VDC Input."** This feeds your LED pixels — it does not power the controller itself (that's Step 3).
 
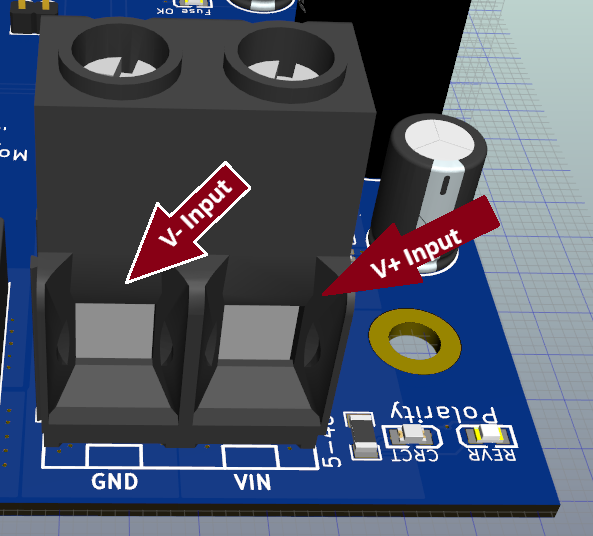
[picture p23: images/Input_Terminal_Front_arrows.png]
Input Terminal Vin/GND labels
- 
- Before inserting any wire, back the terminal screws out enough that the clamp gate fully opens — if you try to force a wire into a closed gate you'll damage the terminal.
- Insert your power supply's positive lead into the Vin opening and the negative lead into the GND opening, then tighten each screw down to clamp the wire firmly.
- Do not power up yet.
 
## Step 2 — Mount your MCU
 
The Waveshare ESP32-S3-ETH-POE module seats into its socket. It's field-replaceable — no soldering required.
 
*Board came complete? The MCU and level shifter are already installed — skip this step.*
 
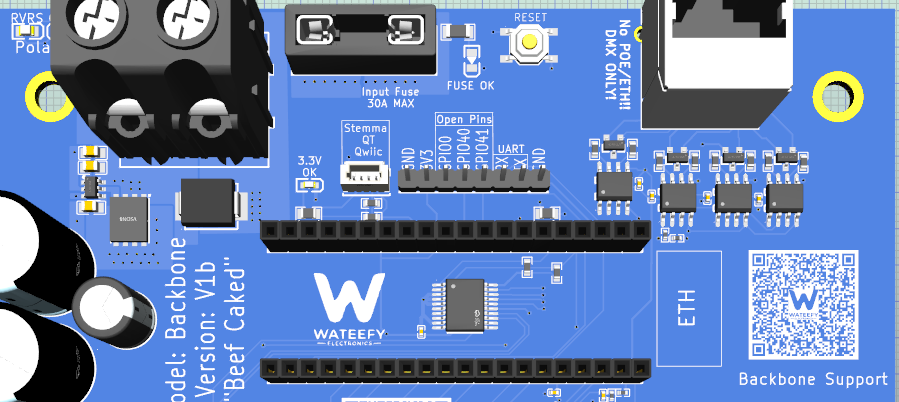
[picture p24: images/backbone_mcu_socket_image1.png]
Waveshare ESP32-S3-ETH-POE seated in socket

 
## Step 3 — Connect Ethernet / PoE
 
**This board MUST be powered by PoE — there is no other way to power the controller.** Plug an Ethernet cable from a PoE-capable switch (802.3af), or from a regular switch plus a PoE injector, into the **ETH** jack.
 
- The controller boots and becomes network-reachable from this connection alone — your pixel supply from Step 1 doesn't need to be powered for this to work.
- How many Backbone nodes your switch can power is limited by your switch's total PoE power budget — that's on you to check against your switch's specs, not something the board limits.
Ethernet/PoE jack
 
## Step 4 — Wire your LED outputs
 
Each of the 8 output channels has its own 3-pole connector (V+ / DATA / GND) near the edge of the board. Connect your pixel strip or fixture's power, data, and ground leads to the channel you want to use. Each channel is individually fused — a fault on one channel won't take down the others.
 
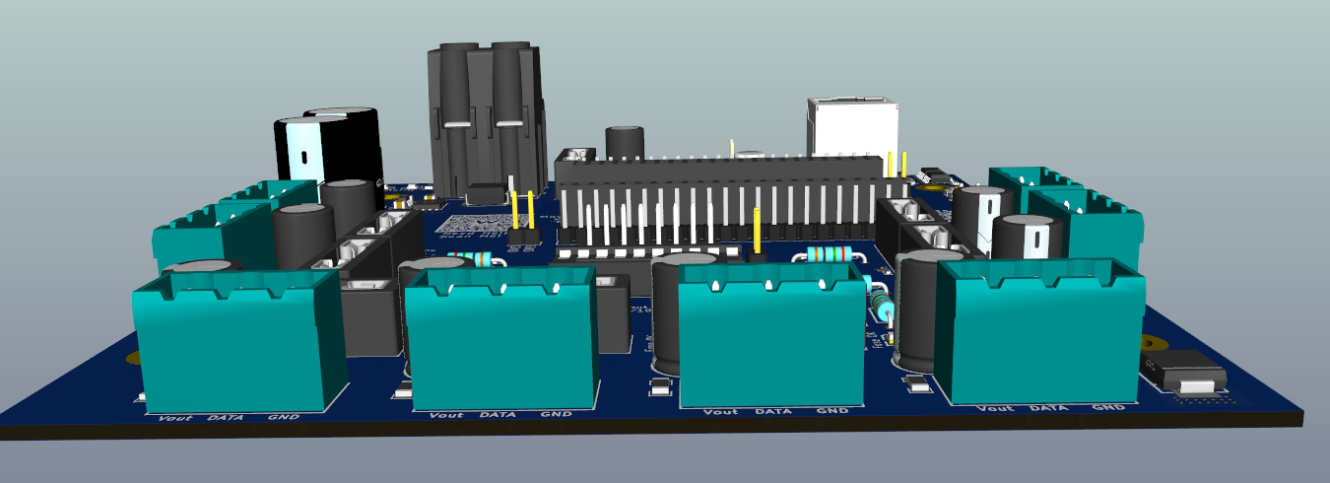
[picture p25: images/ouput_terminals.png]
Output connector with wires landed

 
## Step 5 — Power up and check the indicator LEDs
 
With your pixel supply and Ethernet/PoE both connected, you should see:
 
| Silkscreen label | What it tells you |
|---|---|
| **Polarity** (green) | Input polarity is correct. If this glows **red** instead, power off immediately and check your input wiring — you have it backwards. |
| **Fuse OK** | The main input fuse is intact and the distribution bus is live. If this is dark, check the main fuse. |
| **3.3V OK** | The module's logic rail is up — this only lights once Ethernet/PoE is connected and supplying power (see Step 3). |
 
If all three are lit correctly (green Polarity, Fuse OK, 3.3V OK), your board is alive and ready to be configured over the network through your MCU firmware of choice (WLED, etc.).
 
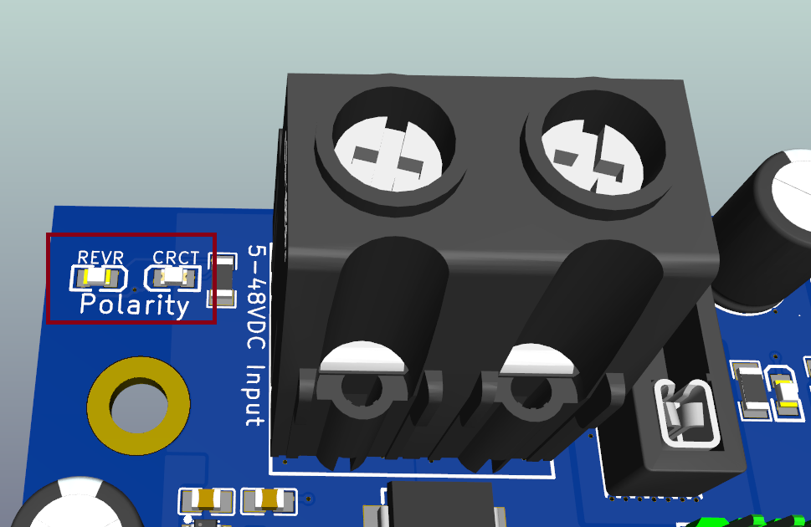
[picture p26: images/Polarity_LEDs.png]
Polarity indicators


Polarity/Fuse OK/3.3V OK LED cluster
 
## Fixed Pin Reference (for firmware configuration)
 
Nothing here needs jumpering — these functions are hardwired to the Waveshare module. You still need to enter the right GPIO numbers in your firmware (WLED, etc.) to use them.
 
| Function | GPIO |
|---|---|
| DMX EN | GPIO46 |
| DMX TX | GPIO45 |
| DMX RX | GPIO42 |
| ADC/MCP SDA | GPIO48 |
| ADC/MCP SCL | GPIO47 |
| STEMMA QT SDA | GPIO39 |
| STEMMA QT SCL | GPIO38 |
 
## Optional — DMX/RS-485 output
 
Node Backbone's DMX is hardwired — just plug your DMX cable into the RJ45-style jack labeled for DMX and set your DMX GPIOs (above) in your firmware. If you're not using DMX, you can ignore this section entirely.
 
**Reminder:** this jack is DMX only — don't confuse it with the Ethernet/PoE jack (see Safety, above).
 
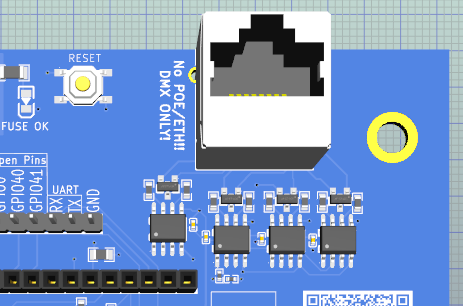
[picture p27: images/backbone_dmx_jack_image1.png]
DMX jack

 
## Optional — Sensor/expansion (I²C)
 
Backbone gives you two ready-to-use I²C access points, both hardwired — no jumpering:
 
- **Onboard ADS1115 (voltage monitor) + MCP23008 (I/O expander):** already wired to the module at the GPIOs listed above — fuse status, Vin, and 5V readings are available as soon as your firmware is configured for them.
- **STEMMA QT / Qwiic connector:** a plug-and-play 4-pin port (3.3V / GND / SDA / SCL) for external I²C sensors — no soldering, no jumper wires, just plug in a STEMMA QT cable.
STEMMA QT/Qwiic connector
 
## Something not working?
 
See the **Troubleshooting** section of the full NODE Backbone Guide, or reach out through the support link printed on the board silkscreen. [Click here to report Issues:](https://github.com/johnvoipguy/WateefyElectronics/issues)

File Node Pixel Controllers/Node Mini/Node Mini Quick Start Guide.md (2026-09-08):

# NODE Mini — Quick Start Guide

*Node Mini, V1b*

Welcome to your NODE Mini! This guide gets you from box to lit-up pixels in about 10 minutes. For full specs, jumper options, and troubleshooting, see the **NODE Mini Full Guide**.

## What you'll need

- NODE Mini board
- Seeed XIAO ESP32-S3 — unless you bought the kit
- TI level shifter, SN74AHCT541N or SN74AHCT245N — unless you bought the kit
- Terminal blocks: 3-pin, 5.08mm, Phoenix-style PCB screw terminal — unless you bought the kit
- Fuses: 30A standard blade (main input), 7.5A standard blade (per-channel output) — unless you bought the kit
- 5–48 VDC power supply sized for your pixel run
- WS281x/SK6812/TM1814-style addressable LED strips or fixtures
- Small Phillips or flathead screwdriver

Node Mini full board overview

## Safety first — read this before wiring anything

- **This board is not automotive-qualified.** It's designed for residential and light-commercial installs — not vehicles, not industrial equipment.
- **Never connect or disconnect wiring with power applied.** Turn off and unplug your power supply first.
- **Watch your polarity on the input terminal.** It's best practice to always double-check Vin and GND before powering up. The board has an ideal-diode circuit to protect against damage from a reversed input, and a Polarity LED that shows green (correct) or red (reversed) so you know at a glance.
- **Match your fuses to your load.** Don't upsize fuses beyond what's printed on the silkscreen — the board's rated limits are there for a reason.
- **Don't confuse the DMX jack with an Ethernet/network jack.** It's RJ45-shaped, but it's DMX/RS-485 only — never plug it into a switch, router, or any network cable. DMX gear only.

## Step 1 — Wire your power input

Find the terminal block marked **"5-48VDC Input."**

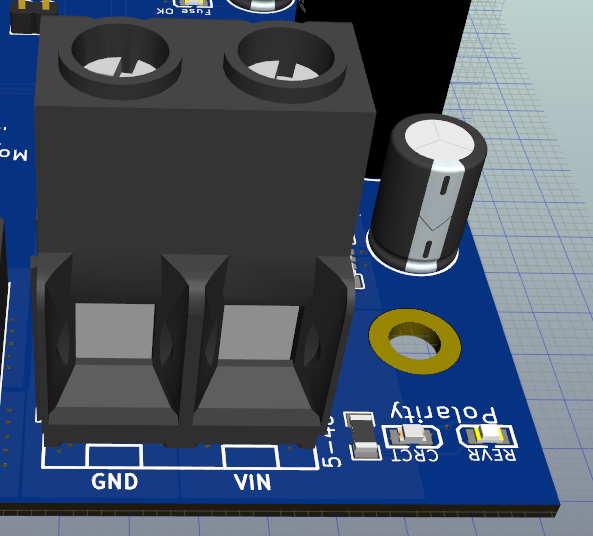
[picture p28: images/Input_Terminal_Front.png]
Input Terminal Vin/GND labels
- 
- Before inserting any wire, back the terminal screws out enough that the clamp gate fully opens — if you try to force a wire into a closed gate you'll damage the terminal.
- Insert your power supply's positive lead into the left (Vin) opening and the negative lead into the right (GND) opening, then tighten each screw down to clamp the wire firmly.
- Do not power up yet.

Input Terminal with wires inserted

## Step 2 — Mount your MCU

The XIAO ESP32-S3 seats into the two 7-pin sockets in the middle top of the board. It's field-replaceable — no soldering required. Line up the USB-C connector with the "USB / Antenna" silkscreen marking and press it firmly into both socket rows.

*Board came complete? The MCU and level shifter are already installed — skip this step.*

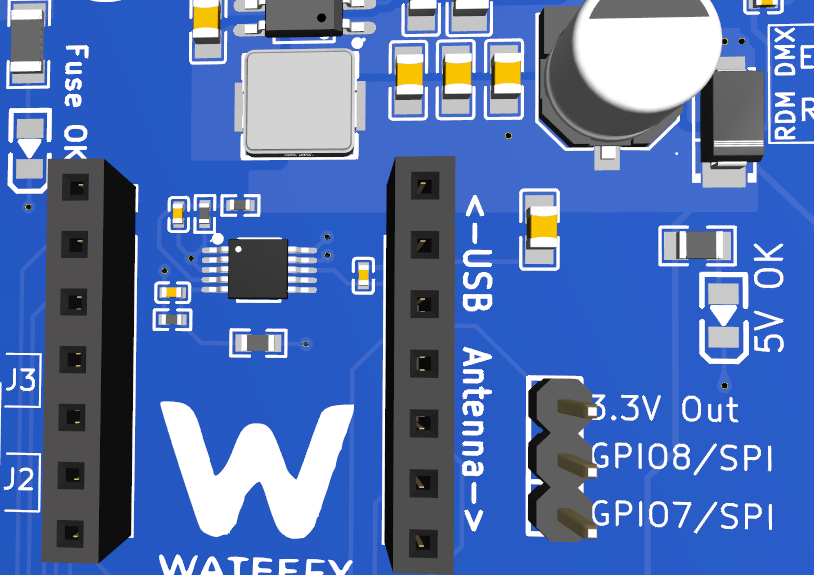
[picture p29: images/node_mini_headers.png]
XIAO ESP32-S3 seated in sockets


## Step 3 — Wire your LED outputs

Each of the 8 output channels has its own 3-pole connector (V+ / DATA / GND) near the edge of the board. Connect your pixel strip or fixture's power, data, and ground leads to the channel you want to use. Each channel is individually fused — a fault on one channel won't take down the others.

Output connector with wires landed

## Step 4 — Power up and check the indicator LEDs

Apply power. You should see, in order:

| Silkscreen label | What it tells you |
|---|---|
| **Polarity** (green) | Input polarity is correct. If this glows **red** instead, power off immediately and check your input wiring — you have it backwards. |
| **Fuse OK** | The main input fuse is intact and the distribution bus is live. If this is dark, check the main fuse. |
| **5V OK** | The onboard 5V logic regulator is up and running, powering your MCU and buffers. |

If all three are lit correctly (green Polarity, Fuse OK, 5V OK), your board is alive and ready to be configured over USB/WiFi through your MCU firmware of choice (WLED, etc.).

Polarity Indicator LEds

Fuse OK/5V OK LED cluster

## Jumper Reference (J1–J4)

| Jumper | Function |
|---|---|
| J1 | Enables SN74AHCT245N level shifter |
| J2 | Enables Fuse Status |
| J3 | Enables ADC voltage monitoring |
| J4 | Enables DMX TX |

## Optional — DMX/RS-485 output

Node Mini includes a 4-port DMX output block, labeled near the RJ45-style jacks. If you're not using DMX, you can ignore this section entirely.

- Only **port 1** supports DMX receive (RX) — the other three ports are transmit-only.
- Look for the silkscreen markings **"RDM DMX"**, **"EN / DMX TX"**, and **"RX"** near the DMX jacks to identify the ports.
- **For DMX (TX):** place the jumper on **J4**.
- **For RDM:** leave **J4** unjumpered — instead, connect jumper wires from **GPIO7** and **GPIO8** to either **EN** or **RX**, depending on your WLED configuration.

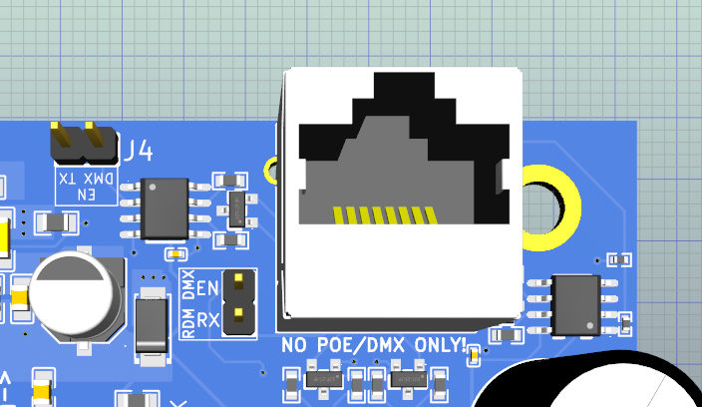
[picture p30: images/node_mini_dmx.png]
DMX jack block


## Optional — Sensor/expansion header (I²C)

Node Mini has an onboard ADS1115 (voltage monitor) and MCP23008 (I/O expander) on their own internal I²C bus, broken out to a small header marked **"SCL ADS/MCP"** / **"SDA ADS/MCP"**. This header does double duty — use it to enable ADS/MCP readings (fuse status, Vin, and 5V readings), or to tap in additional I²C sensors, depending on your project.

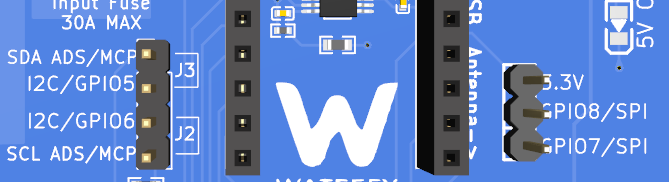
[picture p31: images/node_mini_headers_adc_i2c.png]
SCL/SDA ADS/MCP header


## Something not working?

See the **Troubleshooting** section of the full NODE Mini Guide, or reach out through the support link printed on the board silkscreen. [Click here to report Issues:](https://github.com/johnvoipguy/WateefyElectronics/issues)

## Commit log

2026-10-08 Add NODE Enclosures: Aegis, Bastion 350, Citadel 600
    3MF print files, renders and a family README with dimensions,
    gland/fan specs and reference print settings.
    Claude-Session: https://claude.ai/code/session_01QBAfrCBmndZcixubevEV57
    [NODE-Aegis-Enclosure.3mf, NODE-Bastion-350-Enclosure.3mf, NODE-Citadel-600-Enclosure.3mf]
2026-10-08 Update Bastion 350 3MF with re-saved plate layout
    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
    [NODE-Bastion-350-Enclosure.3mf]
2026-10-08 Enclosures README: note fan mounting holes are printed in
    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
2026-10-08 Enclosures README: clarify screw holes, lengths, screws not included
    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
2026-10-08 Enclosures README: add PSU rail screw length
    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
2026-10-08 Enclosures README: list Ethernet-capable NODE configurations
    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
2026-10-08 Enclosures: fix Bastion render size, add two renders (#10)
    * Enclosures: match Bastion bare-lid render to 4:3, add two renders
    * Enclosures README: describe the lid lip-and-groove seal
    * Enclosures README: tighten lid seal wording
    * Enclosures README: add lid seal close-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
2026-10-08 Docs: link NODE Enclosures from platform and board docs (#11)
    * Docs: point board and platform docs at the NODE Enclosures
    Replace 'no enclosure planned' / 'coming soon' wording with links to the
    printable enclosures, and list Node Enclosures in the root README.
    * README: remove duplicated Node Power..Accepted limitations block
    * Rename stale Flex datasheet to Node Flex-v1.MD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
